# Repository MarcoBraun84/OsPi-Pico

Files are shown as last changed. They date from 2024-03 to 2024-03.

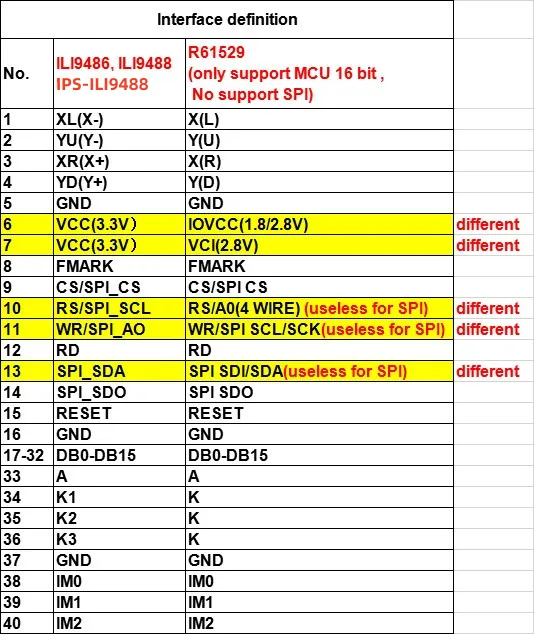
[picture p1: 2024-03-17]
Sonstiges/Pinout ILI9488 Display.webp

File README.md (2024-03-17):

Hier sind alle Projektdatein zum Projekt "OsPi Pico" aus Embedded Systems I vom WS23/24 zu finden.\
Teils wird in "final" und "V1" unterschieden, final bedeutet den Stand am Ende des Projektes, V1 bezieht sich auf die physisch existierenden Platinen.
Sollte an diesen etwas gesucht/geändert werden, kann man sich auzf diese Datein beziehen. Jegliche Verbesserungen oder Weiterentwicklungen sollten aber an den "final" Datein getätigt werden. \

Das Projekt wurde mit Fusion 360 druchgeführt, daher sind viele der umfangreicheren Datein zur Platine nur damit zu öffnen.

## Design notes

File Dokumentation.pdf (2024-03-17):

# PROJEKT OSZI

## „OsPi Pico“ Version 1

## Projektdokumentation

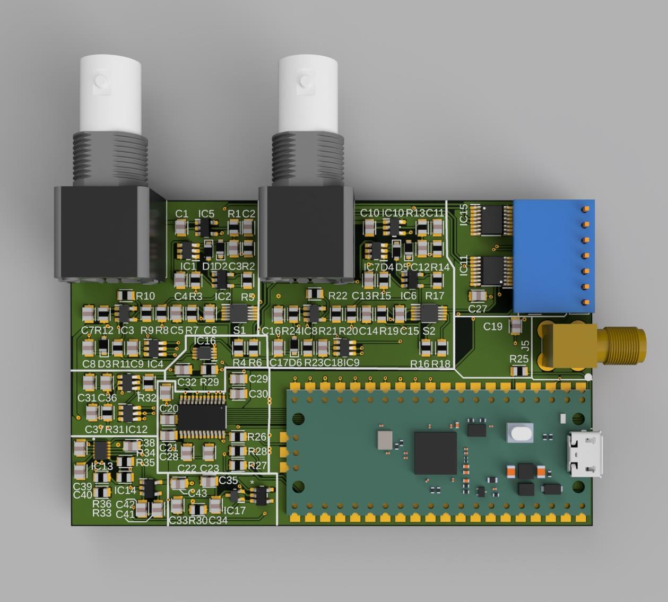
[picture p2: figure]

Embedded Systems I Projekt 2024

Johannes Pautz, Max Sämann

20EIK-IAS

GitHub - Repository (https://github.com/maxsmann/ospi-pico)

## Inhaltsverzeichnis

## 1. Kenndaten

### 1.1 Grundlage: Projekt „RPScope“

Als Grundstein für das Projekt diente das Projekt „RPScope“ (https://hackaday.io/project/188051-rpscope) von „jpgeiro“, welches auf Hackaday.io veröffentlicht wurde. Von hier wurde die Software, sowie der Schaltplan übernommen und überarbeitet. Viele unbekannte Punkte sowie nähere Erklärungen zu Software und Hardware Aufbau sind dort zu finden.

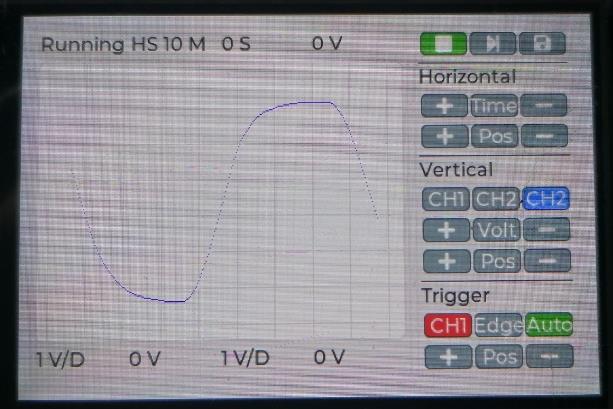
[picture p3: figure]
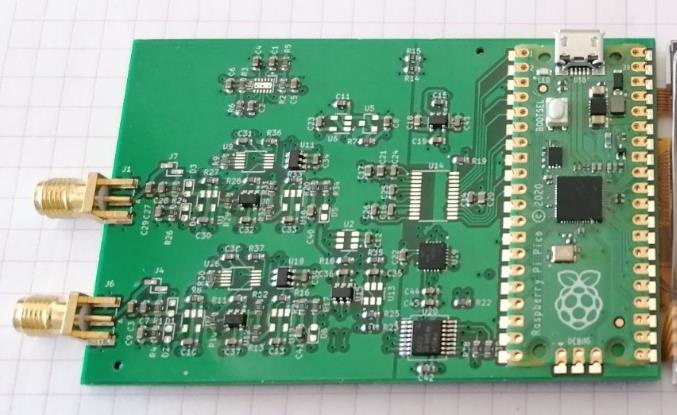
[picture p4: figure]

### 1.2 Eigenschaften der „OsPi Pico“ Platine

- 2 Eingangskanäle mit 100MHz Analog-Bandbreite
- 100Msps ADC mit 8 Bit Auflösung
- 10MHz zur Messung nutzbare Bandbreite pro Kanal
- ±27V Eingangsbereich
- Bedienung über 3,5 Zoll Touch Display
- Stromversorgung über Micro USB (USB-C mit anderem Pi Pico möglich)

## 2. Aufbau

### 2.1 Schaltplan

Die Struktur des Gerätes ist wie folgend aufgebaut:

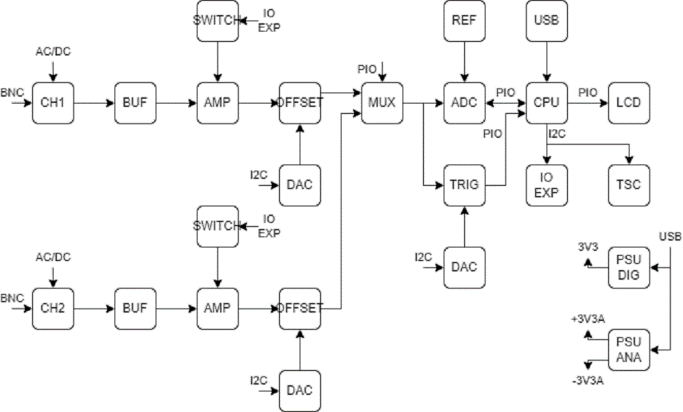
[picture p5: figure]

2.1.1 Belegung Pi Pico

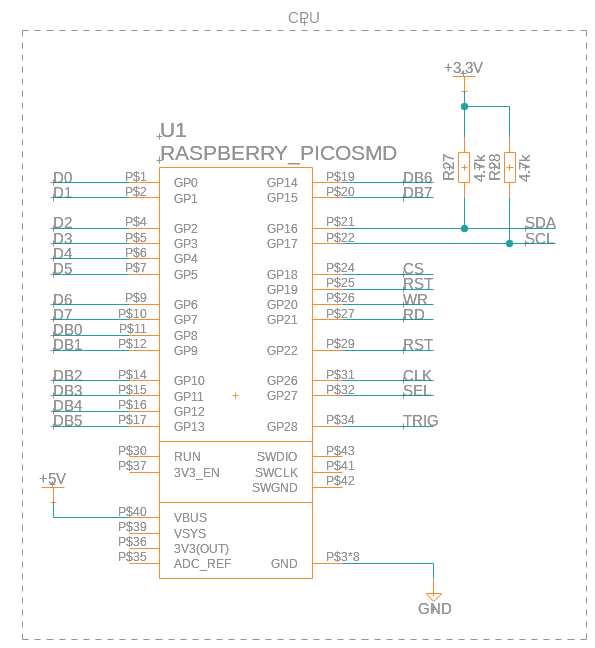
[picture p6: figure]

2.1.2 Stromversorgung Digital

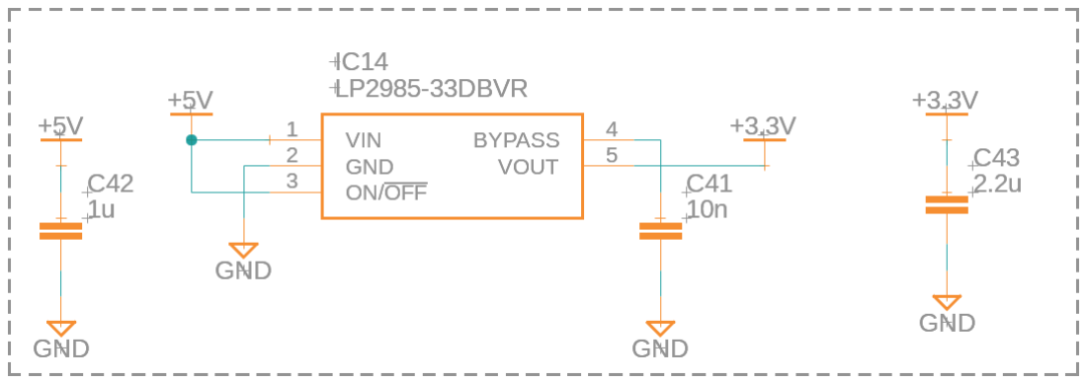
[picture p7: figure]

Die Stromversorgung für den digitalen Teil wird durch einen einfachen Spannungsregler umgesetzt. +5V wird durch den USB-Port am Pi Pico gespeist. Die Kondensatoren C42 und C43 dienen zu Stabilisierung.

C43 kann bei Problemen auch entfernt werden. In unseren Versuchen stellte sich dieser Kondensator nach einiger Zeit als kaputt heraus, was teils bis zum Kurzschluss von +3.3V und somit auch zur Zerstörung des Spannungsreglers folgen kann. Eine Ursache konnte bisher noch nicht ermittelt werden.

2.1.3 Display

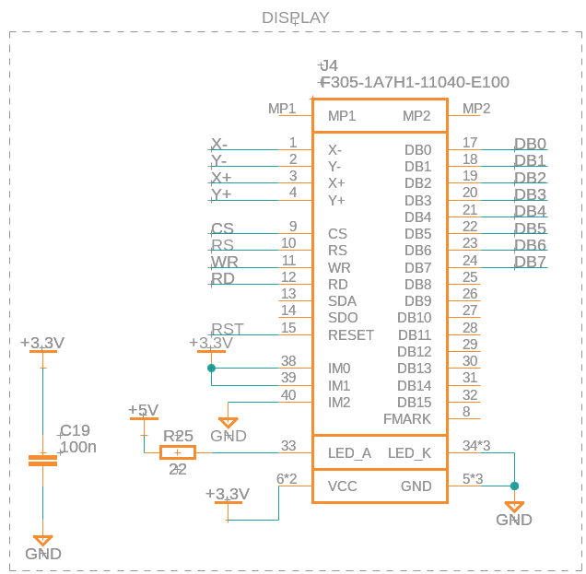
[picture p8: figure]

Das Display ist ein 3,5 Zoll großes resistives Touchdisplay mit einer Auflösung von 480x320 Pixeln. Integriert ist der ILI9488 Displaytreiber. Zu finden ist das Modell auf Aliexpress. (https://de.aliexpress.com/item/32829704426.html)

Das Display ist per 8 Bit parallel Bus nach 8080 Standard an den Pi Pico angebunden. Die Pins 9 bis 12 dienen zur Steuerung des Datenverkehrs.

Leider existiert bisher keine passende Anbindung in der Software für das 8 Bit Interface. Ebenfalls ist auf Charge 1 der Platinen eine Fehlerhafte Verbindung zwischen RST und RS vorhanden.

Näheres zu den Problemen und möglichen Lösungen ist in Kapitel 4 nachzulesen.

Gerät | Pin | Funktion Display Pin | Name | Bemerkung
Touch | 16 | X- | 1 | XL(X-)
Touch | 17 | Y- | 2 | YU(Y-)
Touch | 13 | X+ | 3 | XR(X+)
Touch | 14 | Y+ | 4 | YD(Y+)
PSU¹ | - | GND | 5 | GND
PSU | - | +3.3V | 6 | VCC
PSU | - | +3.3V | 7 | VCC
- | - | - | 8 | FMARK
Pico | 18 | CS | 9 | CS
Pico | 19 | RS | 10 | RS/SCL
Pico | 20 | WR | 11 | WR/AO
Pico | 21 | RD | 12 | RD
- | - | - | 13 | SDA
- | - | - | 14 | SDO
Pico | 22 | RST | 15 | RESET
PSU | - | GND | 16 | GND
Pico | 8-15 | DB0-7 | 17-32 | DB0-15 | Parallel Ansteuerung
PSU | +5V, 22R | Backlight | 33 | A | Anode LED Backlight, +5V durch 22R Wiederstand
PSU | - | GND | 34 | K1 | Kathode LED Backlight
PSU | - | GND | 35 | K2 | Kathode LED Backlight
PSU | - | GND | 36 | K3 | Kathode LED Backlight
PSU | - | GND | 37 | GND
PSU | - | +3.3V | 38 | IM0 | Input Mode: setzt genutzten Eingang fest, hier 8 Bit Parallel
PSU | - | +3.3V | 39 | IM1
PSU | - | GND | 40 | IM2

1 Spannungsversorgung

2.1.4 Touch-Controller

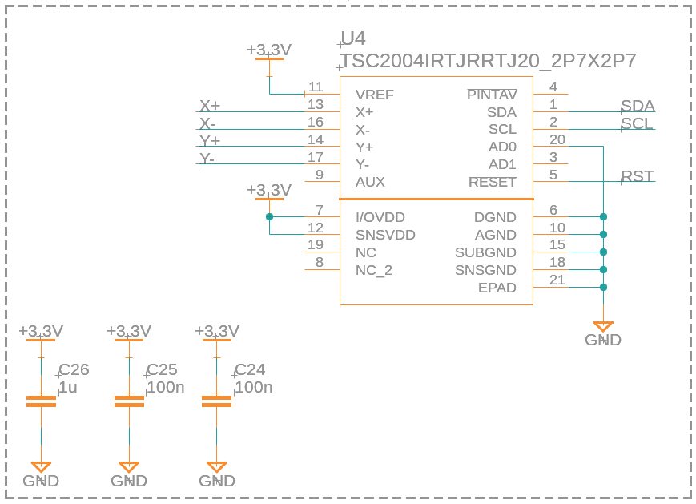
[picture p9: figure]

2.1.5 IO-Expander

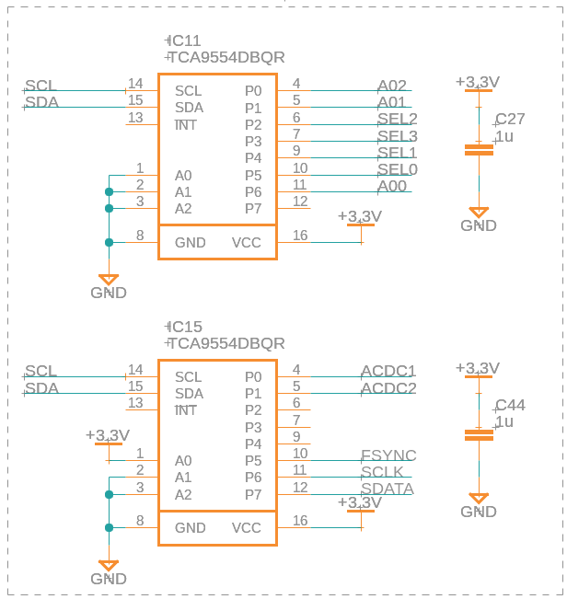
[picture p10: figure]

Der zweite IO-Expander wird im Grunde nur für die AC/DC Umschaltung benötigt. Die Anbindungen FSYNC, SCLK und SDATA vom Funktionsgenerator funktionieren so nicht un müssten umgelegt werden, wie in Kapitel 4 beschrieben.

2.1.6 Funktionsgenerator

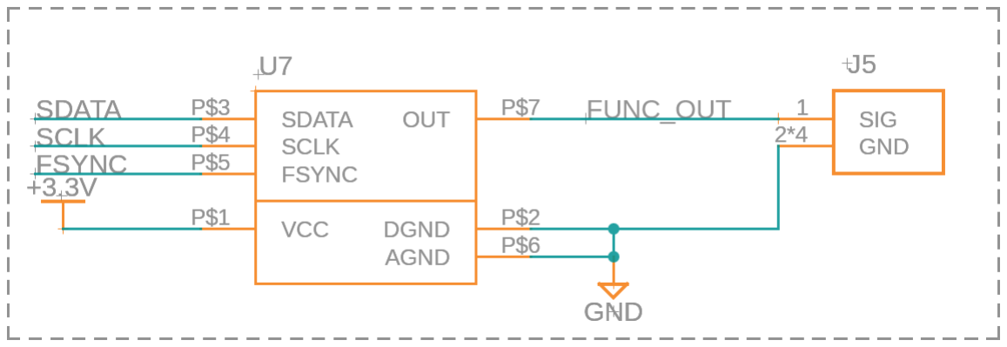
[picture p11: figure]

Der Funktionsgenerator basiert auf einer fertigen Platine mit dem Analog Devices AD9833 IC. Er kann über 3-wire SPI angesteuert werden.

Die Platine selbst wird mit Hilfe einer Steckleiste über der Hauptplatine angebracht. Ein passendes Board kann auf eBay (https://www.ebay.de/itm/284111345234) erworben werden. Da es sich um kein Modell eines wirklich namhaften Herstellers handelt kann folgendes Bild zusammen mit der Modellnummer des ICs als Referenz verwendet werden.

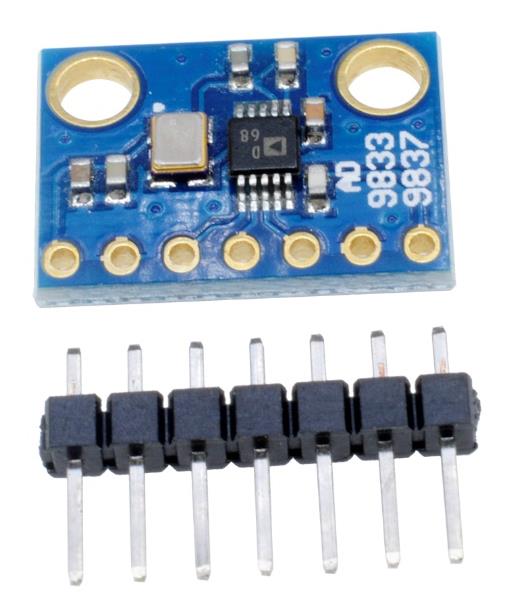
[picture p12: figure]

2.1.7 Stromversorgung analog

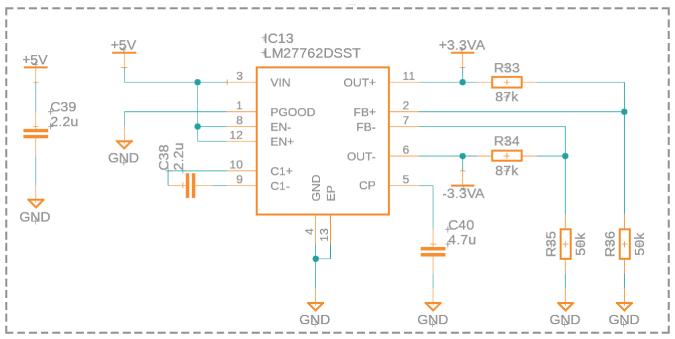
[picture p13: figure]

Die Analoge Stromversorgung wird durch den LM27762 IC ermöglicht. Dieser kann aus der +5VDC Versorgungsspannung sowohl +3.3V als aus -3.3V generieren und ermöglicht so die einfache Nutzung traditioneller OPVs.

2.1.8 Eingangskanäle

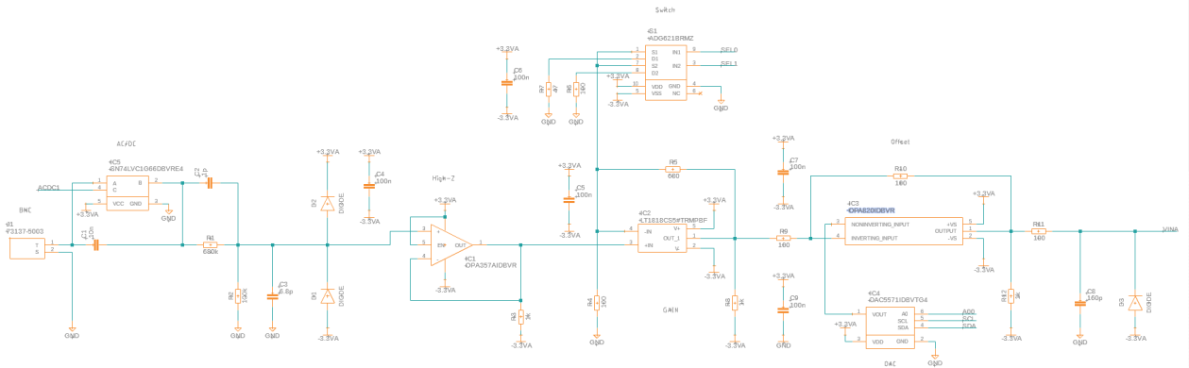
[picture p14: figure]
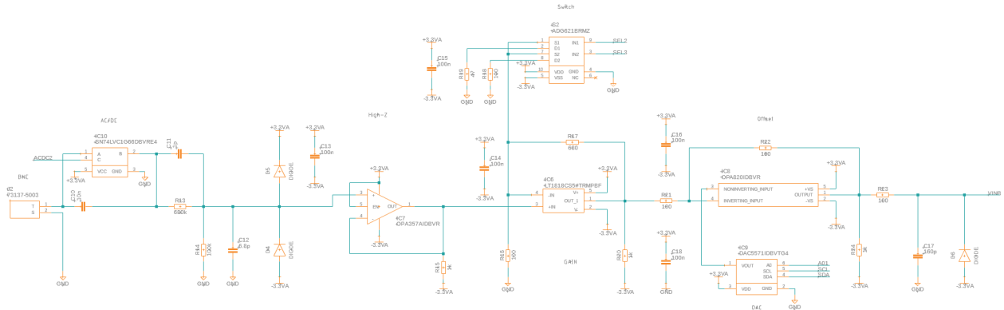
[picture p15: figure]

Die Eingangskanäle bestehen aus 4 Abschnitten. Zuerst kommt die Einkopplung, hier kann auch durch die Analogschalter zwischen AC und DC-Kopplung gewechselt werden. Anschließend kommt die „High-Z“ Stufe, welche dazu dient, die Eingangsimpedanz heraufzusetzen. So werden die Messstrecken nicht durch zusätzliche Stromflüsse belastet, was die Messergebnisse verfälschen würde. Darauf folgt die Gain-Stufe welche je nach gewünschtem Eingangsbereich das Signal „verkleinert“. Die Verstärkung wird durch den Analogschalter oben eingestellt, welcher verschiedene Spannungsteiler darstellt. Am Ende sitzt die Offset-Stufe, hier wird dem Signal eine DC Spannung hinzu gefügt, damit das letztendliche Signal dem 0-VREF Eingangsbereich des ADC entspricht.

2.1.9 Multiplexer

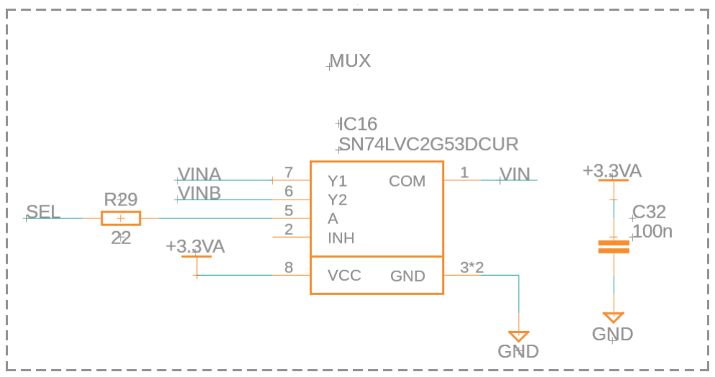
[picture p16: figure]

Normal leitet der Multiplexer Kanal Y1 / VINA auf den Ausgang COM weiter. Liegt SEL am Steuereingang A an, so wird Y1 von COM getrennt und stattdessen Kanal Y2 / VINB auf COM gelegt.

In Betrieb passiert dies blitzschnell um jeweils abwechselnd die Kanäle mit dem ADC samplen zu können.

2.1.10 ADC

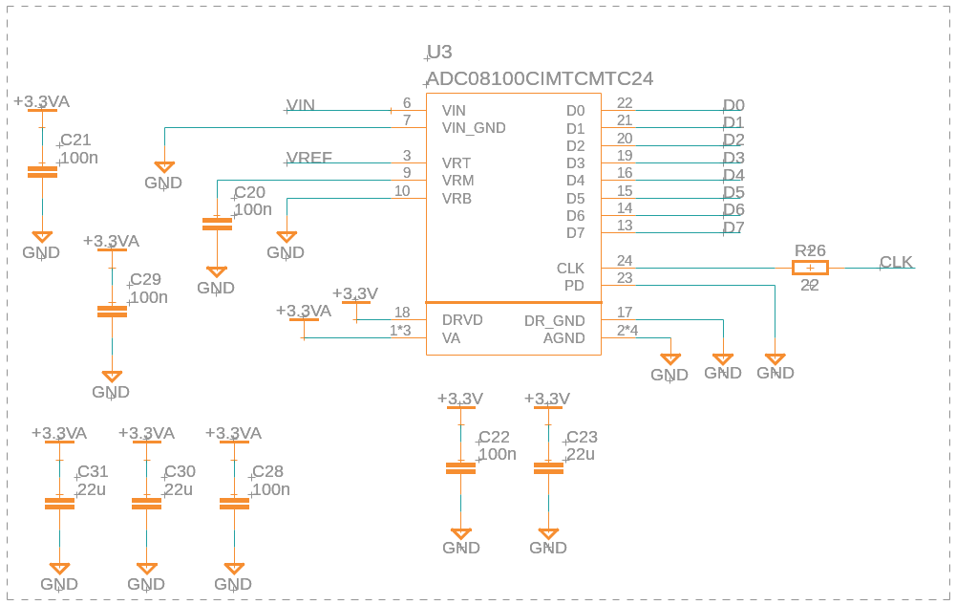
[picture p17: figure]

Der ADC wertet jeweils seinen VIN-Eingang aus, nachdem CLK (vom Pi kommend) von HIGH auf LOW fällt. Bei voller Sample Rate liegt der passende Digitalwert zum VIN Eingang nach 3,5 Samples Verzögerung an den Ausgangspins an.

Der Eingangsbereich beträgt 0V-VREF, in unserem Fall also 0-2V. Das bedeutet, dass das Eingangssignal vorher durch die Offset-Stufe im Analogeingang verschoben werden muss. 0V im Eingangssignal muss zu 1V am ADC Eingang werden.

Die Daten des ADCs werden über 8 Bit parallel Bus (1 Pin für jedes Bit an Auflösung) an den Pi Pico übertragen. Das ermöglicht uns deutlich höheren Durchsatz als zum Beispiel bei I2C oder SPI.

2.1.11 Referenzspannungsquelle

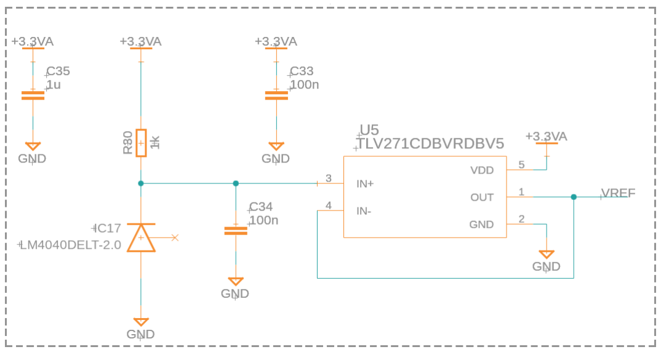
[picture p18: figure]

Die Referenzspannung wird mit Hilfe einer hochgenauen Z-Diode erzeugt. Da diese Referenzspannung aber bei Belastung einbrechen würde, wird ein OPV als Impedanzwandler genutzt, um den Strom über die Z-Diode möglichst nah an 0 zu halten.

2.1.12 Trigger

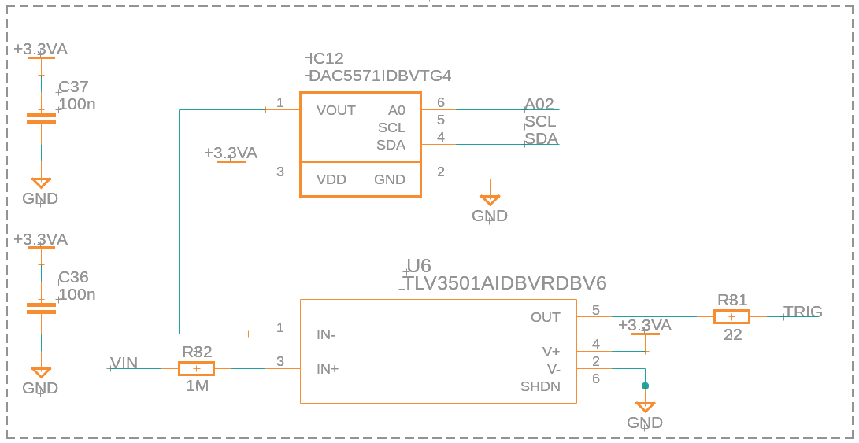
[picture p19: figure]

Das Herzstück des Triggers ist der TLV3501 Highspeed-Komparator. Er gibt über das TRIG-Signal ein HIGH Pegel an den Pi Pico, wenn die Eingestellte Spannung im Eingangssignal erreicht wird. Der Spannungspegel wird durch einen per I2C an den Pico angebundenen DAC eingestellt.

Für VIN sollte VINA verwendet werden, das ist ein Fehler, der beim Layout unterlaufen ist, mehr dazu in Kapitel 4.

### 2.2 Platine

2.2.1 Materialliste

Für das Gerät ergibt sich abgesehen von der Platine selbst und dem Display folgende Materialliste:

Menge | Wert | Bauteil
10 | 100 | R_CHIP-0805(2012-METRIC)
2 | 100k | R_CHIP-0805(2012-METRIC)
23 | 100n | C_CHIP-0805(2012-METRIC)
3 | 10n | C_CHIP-0805(2012-METRIC)
2 | 160p | C_CHIP-0805(2012-METRIC)
1 | 1M | R_CHIP-0805(2012-METRIC)
7 | 1k | R_CHIP-0805(2012-METRIC)
2 | 1p | C_CHIP-0805(2012-METRIC)
5 | 1u | C_CHIP-0805(2012-METRIC)
3 | 2.2u | C_CHIP-0805(2012-METRIC)
4 | 22 | R_CHIP-0805(2012-METRIC)
3 | 22u | C_CHIP-0805(2012-METRIC)
2 | 4.7k | R_CHIP-0805(2012-METRIC)
1 | 4.7u | C_CHIP-0805(2012-METRIC)
2 | 47 | R_CHIP-0805(2012-METRIC)
2 | 50k | R_CHIP-0805(2012-METRIC)
2 | 6.8p | C_CHIP-0805(2012-METRIC)
2 | 680 | R_CHIP-0805(2012-METRIC)
2 | 680k | R_CHIP-0805(2012-METRIC)
2 | 73137-5003 | 73137-5003
2 | 87k | R_CHIP-0805(2012-METRIC)
1 | AD9833FUNCGEN | AD9833FUNCGEN
1 | ADC08100CIMTCMTC24 | ADC08100CIMTCMTC24
2 | ADG621BRMZ | ADG621BRMZ
3 | DAC5571IDBVTG4 | DAC5571IDBVTG4
6 | DIODE | DIODE_DO-219-AC(SOD323F)
1 | F305-1A7H1-11040-E100 | F305-1A7H1-11040-E100
1 | LM27762DSST | LM27762DSST
1 | LM4040DELT-2.0 | LM4040DELT-2.0
1 | LP2985-33DBVR | LP2985-33DBVR
2 | LT1818CS5#TRMPBF | LT1818CS5#TRMPBF
2 | OPA357AIDBVR | OPA357AIDBVR
2 | OPA820IDBVR | OPA820IDBVR
1 | PCB.SMAFRA.HT | PCB.SMAFRA.HT
1 | RASPBERRY_PICOSMD | RASPBERRY_PICOSMD
2 | SN74LVC1G66DBVRE4 | SN74LVC1G66DBVRE4
1 | SN74LVC2G53DCUR | SN74LVC2G53DCUR
2 | TCA9554DBQR | TCA9554DBQR
1 | TLV271CDBVRDBV5 | TLV271CDBVRDBV5
1 | TLV3501AIDBVRDBV6 | TLV3501AIDBVRDBV6
1 | TSC2004IRTJRRTJ20_2P7X2P7 | TSC2004IRTJRRTJ20_2P7X2P7

Alle nicht-Standard SMD-Komponenten sind zur einfacheren Bestellung als Projektliste auf Mouser verfügbar:
https://www.mouser.com/ProjectManager/ProjectDetail.aspx?AccessID=aab402505e

2.2.2 Bestückung

Die | Bestückung | der | einzelnen
Komponenten ist wie folgt:
Part | Value | Device
C1 | 10n | C_CHIP-0805(2012-METRIC)
C2 | 1p | C_CHIP-0805(2012-METRIC)
C3 | 6.8p | C_CHIP-0805(2012-METRIC)
C4 | 100n | C_CHIP-0805(2012-METRIC)
C5 | 100n | C_CHIP-0805(2012-METRIC)
C6 | 100n | C_CHIP-0805(2012-METRIC)
C7 | 100n | C_CHIP-0805(2012-METRIC)
C8 | 160p | C_CHIP-0805(2012-METRIC)
C9 | 100n | C_CHIP-0805(2012-METRIC)
C10 | 10n | C_CHIP-0805(2012-METRIC)
C11 | 1p | C_CHIP-0805(2012-METRIC)
C12 | 6.8p | C_CHIP-0805(2012-METRIC)
C13 | 100n | C_CHIP-0805(2012-METRIC)
C14 | 100n | C_CHIP-0805(2012-METRIC)
C15 | 100n | C_CHIP-0805(2012-METRIC)
C16 | 100n | C_CHIP-0805(2012-METRIC)
C17 | 160p | C_CHIP-0805(2012-METRIC)
C18 | 100n | C_CHIP-0805(2012-METRIC)
C19 | 100n | C_CHIP-0805(2012-METRIC)
C20 | 100n | C_CHIP-0805(2012-METRIC)
C21 | 100n | C_CHIP-0805(2012-METRIC)
C22 | 100n | C_CHIP-0805(2012-METRIC)
C23 | 22u | C_CHIP-0805(2012-METRIC)
C24 | 100n | C_CHIP-0805(2012-METRIC)
C25 | 100n | C_CHIP-0805(2012-METRIC)
C26 | 1u | C_CHIP-0805(2012-METRIC)
C27 | 1u | C_CHIP-0805(2012-METRIC)
C28 | 100n | C_CHIP-0805(2012-METRIC)
C29 | 100n | C_CHIP-0805(2012-METRIC)
C30 | 22u | C_CHIP-0805(2012-METRIC)
C31 | 22u | C_CHIP-0805(2012-METRIC)
C32 | 100n | C_CHIP-0805(2012-METRIC)
C33 | 100n | C_CHIP-0805(2012-METRIC)
C34 | 100n | C_CHIP-0805(2012-METRIC)
C35 | 1u | C_CHIP-0805(2012-METRIC)
C36 | 100n | C_CHIP-0805(2012-METRIC)
C37 | 100n | C_CHIP-0805(2012-METRIC)
C38 | 2.2u | C_CHIP-0805(2012-METRIC)
C39 | 2.2u | C_CHIP-0805(2012-METRIC)
C40 | 4.7u | C_CHIP-0805(2012-METRIC)
C41 | 10n | C_CHIP-0805(2012-METRIC)
C42 | 1u | C_CHIP-0805(2012-METRIC)
C43 | 2.2u | C_CHIP-0805(2012-METRIC)
C44 | 1u | C_CHIP-0805(2012-METRIC)
D1 | DIODE | DIODE_DO-219- AC(SOD323F)
D2 | DIODE | DIODE_DO-219-AC(SOD323F)
D3 | DIODE | DIODE_DO-219-AC(SOD323F)
D4 | DIODE | DIODE_DO-219-AC(SOD323F)
D5 | DIODE | DIODE_DO-219-AC(SOD323F)
D6 | DIODE | DIODE_DO-219-AC(SOD323F)
IC1 | OPA357AIDBVR | OPA357AIDBVR
IC2 | LT1818CS5#TRMPBF | LT1818CS5#TRMPBF
IC3 | OPA820IDBVR | OPA820IDBVR
IC4 | DAC5571IDBVTG4 | DAC5571IDBVTG4
IC5 | SN74LVC1G66DBVR E4 | SN74LVC1G66DBVRE4
IC6 | LT1818CS5#TRMPBF | LT1818CS5#TRMPBF
IC7 | OPA357AIDBVR | OPA357AIDBVR
IC8 | OPA820IDBVR | OPA820IDBVR
IC9 | DAC5571IDBVTG4 | DAC5571IDBVTG4
IC10 | SN74LVC1G66DBVR E4 | SN74LVC1G66DBVRE4
IC11 | TCA9554DBQR | TCA9554DBQR
IC12 | DAC5571IDBVTG4 | DAC5571IDBVTG4
IC13 | LM27762DSST | LM27762DSST
IC14 | LP2985-33DBVR | LP2985-33DBVR
IC15 | TCA9554DBQR | TCA9554DBQR
IC16 | SN74LVC2G53DCUR | SN74LVC2G53DCUR
IC17 | LM4040DELT-2.0 | LM4040DELT-2.0
J1 | 73137-5003 | 73137-5003
J2 | 73137-5003 | 73137-5003
J4 | F305-1A7H1-11040-E100 | F305-1A7H1-11040-E100
J5 | PCB.SMAFRA.HT | PCB.SMAFRA.HT
R1 | 680k | R_CHIP-0805(2012-METRIC)
R2 | 100k | R_CHIP-0805(2012-METRIC)
R3 | 1k | R_CHIP-0805(2012-METRIC)
R4 | 100 | R_CHIP-0805(2012-METRIC)
R5 | 680 | R_CHIP-0805(2012-METRIC)
R6 | 100 | R_CHIP-0805(2012-METRIC)
R7 | 47 | R_CHIP-0805(2012-METRIC)
R8 | 1k | R_CHIP-0805(2012-METRIC)
R9 | 100 | R_CHIP-0805(2012-METRIC)
R10 | 100 | R_CHIP-0805(2012-METRIC)
R11 | 100 | R_CHIP-0805(2012-METRIC)
R12 | 1k | R_CHIP-0805(2012-METRIC)
R13 | 680k | R_CHIP-0805(2012-METRIC)
R14 | 100k | R_CHIP-0805(2012-METRIC)
R15 | 1k | R_CHIP-0805(2012-METRIC)
R16 | 100 | R_CHIP-0805(2012-METRIC)
R17 | 680 | R_CHIP-0805(2012-METRIC)
R18 | 100 | R_CHIP-0805(2012-METRIC)
R19 | 47 | R_CHIP-0805(2012-METRIC)
R20 | 1k | R_CHIP-0805(2012-METRIC)
R21 | 100 | R_CHIP-0805(2012-METRIC)
R22 | 100 | R_CHIP-0805(2012-METRIC)
R23 | 100 | R_CHIP-0805(2012-METRIC)
R24 | 1k | R_CHIP-0805(2012-METRIC)
R25 | 22 | R_CHIP-0805(2012-METRIC)
R26 | 22 | R_CHIP-0805(2012-METRIC)
R27 | 4.7k | R_CHIP-0805(2012-METRIC)
R28 | 4.7k | R_CHIP-0805(2012-METRIC)
R29 | 22 | R_CHIP-0805(2012-METRIC)
R30 | 1k | R_CHIP-0805(2012-METRIC)
R31 | 22 | R_CHIP-0805(2012-METRIC)
R32 | 1M | R_CHIP-0805(2012-METRIC)
R33 | 87k | R_CHIP-0805(2012-METRIC)
R34 | 87k | R_CHIP-0805(2012-METRIC)
R35 | 50k | R_CHIP-0805(2012-METRIC)
R36 | 50k | R_CHIP-0805(2012-METRIC)
S1 | ADG621BRMZ | ADG621BRMZ
S2 | ADG621BRMZ | ADG621BRMZ
U1 | RASPBERRY_PICOS MD | RASPBERRY_PICOSMD
U3 | ADC08100CIMTCMT C24 | ADC08100CIMTCMTC24
U4 | TSC2004IRTJRRTJ20 _2P7X2P7 | TSC2004IRTJRRTJ20_2P7X2 P7
U5 | TLV271CDBVRDBV5 | TLV271CDBVRDBV5
U6 | TLV3501AIDBVRDBV 6 | TLV3501AIDBVRDBV6
U7 | AD9833FUNCGEN | AD9833FUNCGEN

## 3. Software

3.1.1 Programmierung des Pi Pico mit Micropython

Zuerst muss die Firmware von der Raspberry Pi Website heruntergeladen werden und dann auf dem Pi gezogen werden. Dafür hält man den „BOOTSEL“ Knopf am Pico gedrückt, während man diesen per USB verbindet. Dieser taucht als externer Speicher auf dem PC auf, die Firmwaredatei muss nun nur auf diesen Speicher kopiert werden. Anschließend startet der Pico neu und kann nun in der Entwicklungsumgebung gefunden werden. Als Entwicklungsumgebung kann entweder die Thonny DIE oder Visual Studio Code mit der Micropico Erweiterung dienen.

Einzelne .py Code-Dateien können direkt aus der IDE heraus auf dem Pico ausgeführt werden, wenn es sich aber wie in unserem Fall um mehrere Dateien handelt, müssen die Dateien mit Hilfe des in die IDE integrierten Dateibrowsers auf den Pico übertragen werden. Bei größeren Programmen hängt dieser sich gerne während des Kopierens auf, was einen Neustart und eine Neuinstallation der Firmware erforderten. Hier hat sich als wirksam herausgestellt, eine Hälfte zu übertragen, den Pico am USB-Port ab- und wieder anzustecken und dann die zweite Hälfte zu kopieren.

3.1.2 Schwierigkeiten der Nutzung externer Bibliotheken mit Micropython

Für die Nutzeroberfläche des Oszilloskops wird die Grafikbibliothek lvgl ² benötigt, welche offiziell über lv_micropython³ auch die Verwendung unter Micropython unterstützt. In unserem Fall kann aber maximal einer 8.X Version von lvgl verwendet werden, da sich ab Version 9 wieder einige Codes geändert haben.

Zusätzlich stellt sich die Installation mehr als kompliziert heraus. Die passende Firmware für den Pi muss vorerst selbst auf einem Linux Rechner oder auf Windows über WSL kompiliert werden.

Dafür müssen folgende Schritte im Terminal durchlaufen werden:

1 | git clone https://github.com/lvgl/lv_micropython.git
2 | cd lv_micropython
3 | git submodule update --init --recursive lib/lv_bindings
4 | make -C ports/rp2 BOARD=PICO submodules
5 | make -j -C mpy-cross
6 | make -j -C ports/rp2 BOARD=PICO USER_C_MODULES=../../lib/lv_bindings/bindings.cmake

Die benötigte .uf2-Firmwaredatei, in der die Bibliothek integriert wurde, kann bei Erfolg anschließend im Verzeichnis lv_micropyton/Ports/rp2/build-PICO/firmware.uf2 gefunden und auf den Pico kopiert werden.

Dieser Prozess birgt jedoch einige Eigenheiten und neigt dazu, mit kryptischen Fehlermeldungen abzubrechen. In diesem Fall muss der Prozess komplett von neuem

2 https://github.com/lvgl/lvgl

3 https://github.com/lvgl/lv_micropython gestartet werden. Sollte eine Fehlermeldung fehlende Packages wie z.B. gcc-… bemängeln, so sollte vor dem Neustart das Package mit „sudo apt-get install [Packagename]“ installiert werden.

## 4. Bestehende Probleme

4.1.1 Problem Abweichende Software

Leider befindet sich die Software nicht auf dem richtigen Hardwarestand, was dazu führt dass die Platine derzeit nicht nutzbar ist. Einige Komponenten weichen dadurch ab oder können nicht korrekt angesteuert werden. Dadurch ergeben sich folgende Probleme:

Displayanbindung

Das Display ist softwareseitig über den SPI-Bus angebunden, welcher auf dieser Hardware gar nicht genutzt wird. Das Display ist stattdessen übern eine 8 Bit Parallel Anbindung nach 8080 Standard mit den Pins 8 bis 15 des Picos verbunden. Für diese Anbindung liegt kein passender Display Treiber vor.

Umsetzung des Triggers

Der Trigger ist softwareseitig mit PWM direkt über einen Pin des Picos umgesetzt. Auf dem Board ist jedoch schon eine ausgebautere Variante mit Komparator und einem eigenen DAC zur Einstellung der Spannungsschwelle verbaut. Für den DAC existiert eine Einbindung jedoch ist diese sehr simpel und enthält derzeit noch keine Möglichkeit zur Auswahl der einzelnen DACS. Von diesen befinden sich 3 identische auf dem Board (jeweils einer zur Einstellung des Offsets), was die Auswahlpins A00-A02 erfordert. Diese sind aber softwareseitig noch nicht umgesetzt.

Touch Controller

In der Software wird ein XPT2046 Touch Controller verwendet, auf dem Board befindet sich aber das Modell TSC2004 was noch stattdessen implementiert werden müsste. Möglicherweise ist auch der Code für den XPT2046 für den TSC2004 nutzbar.

4.1.2 Fehler im neuen Platinenlayout

Fälschliche Verbindung von RESET und RS

Beim Erstellen der neuen Platine sind ein paar Fehler nicht ausgeblieben. Fälschlicherweise wurden die beiden Steuersignale RESET und RS miteinander verbunden. Eigentlich sollte jedoch RESET einzeln zu Pin 15 am Display und Pin 5 am Touch Controller gehen. Jedoch wurden diese aufgrund von mangelndem Verständnis ebenfalls über Display Pin 10 „RS“ verbunden.
Der Fehler kann durch gezielt Trennung der Leiterbahn zwischen Display und Touch Controller sowie zwischen den RESET und RS-Pin am Pico behoben werden, um zumindest die Display Funktionalität gewährleisten zu können. Jedoch geht so die RESET Funktionalität verloren, dafür müsste ein Draht gelegt werden.

SPI-Anbindung des Funktionsgenerators

Der Funktionsgenerator wird über den SPI-Bus des Pi Pico angebunden, jedoch wurde durch Versäumnis diese Verbindung auf den IO-Expander gelegt. Der IO-Expander ist nicht fähig mit seinen Ein-/Ausgängen einen weiteren SPI-Bus zu erzeugen. Die SPI-Pins des Funktionsgenerators müssten and eine SPI-Schnittstelle des Pi Picos angebunden werden.

Leider ist hier kein geeigneter Pin mehr verfügbar. Würde eine Umstellung des Displays auf SPI erfolgen, könnte der Funktionsgenerator wohlmöglich mit an denselben Bus angebunden werden. So muss dieser Punkt in Schaltplan sowie dem Platinenlayout überarbeitet werden.

### 4.2 Mögliche Problemlösungen

4.2.1 Displayansteuerung

Um das Display korrekt nutzen zu können, könnten zwei Herangehensweisen genutzt werden:

Neuer Displaytreiber

Damit das Display über den 8 Bit 8080 Parallel-Port genutzt werden kann, muss ein passender Display Treiber gefunden und angepasst / geschrieben werden. Vorteil davon wäre, dass das Display über diese Schnittstelle deutlich schneller angesteuert werden kann als über SPI, da auch die 8-fache Bandbreite zur Verfügung steht. So ließen sich in etwa 60 Bilder/Sekunde realisieren, das Display unterstützt maximal 70.

Anbindung auf SPI umbauen

Durch Drähte oder eine neue Platine könnte das Display wieder, wie in der Software spezifiziert per SPI angebunden werden. Hierfür würden die Pins am Pico frei werden, welche vorher für die parallele Übertragung genutzt wurden. Daraus würde sich folgende Belegung am Display ergeben:

Gerät | Pin | Funktion Display Pin | Name | Bemerkung
Touch | 16 | X- | 1 | XL(X-)
Touch | 17 | Y- | 2 | YU(Y-)
Touch | 13 | X+ | 3 | XR(X+)
Touch | 14 | Y+ | 4 | YD(Y+)
PSU | - | GND | 5 | GND
PSU | - | +3.3V | 6 | VCC
PSU | - | +3.3V | 7 | VCC
- | - | - | 8 | FMARK
Pico | 9 | CS | 9 | CS
Pico | 10 | SCL | 10 | RS/SCL
Pico | 8 | AO/DC | 11 | WR/AO
- | - | - | 12 | RD
Pico | 11 | MOSI | 13 | SDA
Pico | 12 | MISO | 14 | SDO
Pico | 22 | RST | 15 | RESET
PSU | - | GND | 16 | GND
- | - | - | 17-32 | DB0-15 | Parallel Ansteuerung
PSU | 22R | Backlight | 33 | A | Anode LED Backlight
PSU | - | GND | 34 | K1 | Kathode LED Backlight
PSU | - | GND | 35 | K2 | Kathode LED Backlight
PSU | - | GND | 36 | K3 | Kathode LED Backlight
PSU | - | GND | 37 | GND
PSU | - | +3.3V | 38 | IM0 | Input Mode: setzt genutzten Eingang fest, hier 4 Wire SPI
PSU | - | +3.3V | 39 | IM1
PSU | - | +3.3V | 40 | IM2

Im Vergleich zur parallelen Anbindung kann das Display nicht so schnell aktualisiert werden, jedoch sollte ein Oszilloskop auch mit grade mal 10 Bildern/Sekunde⁴ nutzbar sein. Nach eigenem Empfinden würde die Pin-Ersparnis und die Verfügbarkeit fertiger Bibliotheken hier zum Vorteil von SPI überwiegen.

4.2.2 Softwareanpassung

Trigger

Damit der Trigger wie gewollt funktioniert, muss der PWM-Wert, der von der Scope Funktion ausgegeben wird in den passenden Wert für den DAC5571 IC in der Trigger Schaltung gewandelt werden. Schließlich muss dieser Wert noch auf den IC übertragen werden, indem der Adress-Pin A02 HIGH gesetzt werden und die passenden Daten über I2C ausgegeben werden. Währenddessen müssen die Pins A00 und A01 der identischen DACs für den Offset der Eingänge LOW gezogen werden. Das Trigger Signal selbst erfolgt dann über das TRIG-Signal, welches als Eingang im Pi Pico umgesetzt werden müsste und dort an die Nutzeroberfläche übermittelt werden muss.

Die genaue Adressierung kann auf Seite 15 des Datenblatts⁵ nachgelesen werden.

4.2.3 Verbesserung des Platinenlayouts

Behebung RS/RST Verbindung

Um die Reset-Verbindung korrekt umzusetzen, wird diese vom RS-Potenzial getrennt und eine eigene Leiterbahn gelegt. Das wurde bereits in der aktuellen Version des Layouts korrigiert.

+3.3VA und +3.3V Güsse durch GND-Guss ersetzen

Für eine neue Revision der Platine sollten die Polygongüsse für +3.3VA und +3.3V auf der Oberseite entfernt und durch GND-Güsse ersetzt werden. Dadurch können einige Vias und GND-Leiterbahnen entfernt werden. Dafür müssen nun für die Spannungsversorgung neue Leiterbahnen verlegt werden.

Montagepunkte

Ein kleines, aber nicht unwichtiges Manko der aktuellen Revision sind fehlende Montagepunkte, wie z.B. Löcher für Schrauben/Abstandshalter. Solche Merkmale sollten hinzugefügt werden.

4
https://www.reddit.com/r/esp32/comments/r5awqp/made_a_refresh_rate_test_comparison_between_the/

5 https://www.ti.com/lit/ds/symlink/dac5571.pdf

## 5. Fazit

### 5.1 Stand zu Projektende

Zu Projektende ist das Gerät nicht funktionsfähig. Das rührt aus einer Kombination von Hardwareproblemen und dem, dass die Software in ihrer jetzigen Form nicht mit der Platine funktioniert. Bis zur Präsentation wird probiert zumindest das Display mit neuem C-Code etwas anzeigen zu lassen. Es existiert eine Platine auf der alles bis auf den zweiten Eingangskanal aufgebaut und funktionsfähig ist.

### 5.2 Offene Punkte

- Displayansteuerung durch passenden Displaytreiber oder Hardwareänderung auf SPI realisieren
- Frequenzgenerator per SPI anbinden, bzw. wenn das Display parallel laufen soll Alternative finden oder komplett weglassen
- Berechnung von RMS und Frequenzwerten in der Benutzeroberfläche
- Firmware verstehen und anpassen oder bestenfalls in C neu schreiben
- Montagepunkte zur Platine hinzufügen
- Gehäuse für das Gerät

Leider endet das Projekt nicht mit einem vorzeigbaren funktionierenden Gerät.

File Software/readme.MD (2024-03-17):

Es existieren 3 verschiedene Softwareversionen:\
### original_fixed
Die vollständige Originalsoftware, so abgeändert dass main.py und scope.py fehlerfrei laufen\
(Behebung lv.color_SIZE und zu großer Speicherbedarf) 

### simple_test.py
Dieses kurze Skript liest die Daten der Datenbus Pins per normalem Code und gibt diese auf dem Terminal aus, zusätzlich wird ein passende Clock Signal generiert.\
Dient nur zu simplen Testzwecken 

### measure_only
Entpsricht dem Originalcode, jedoch wurde alles was mit der Nutzeroberfläche oder demm Display zutun hat entfernt. Dient der reinen Analogwertaufnahme (wenn funktional implementiert) 

---

Bei den .uf2 Datein ahndelt es sich um Firmwaredatein für den Pi Pico, einerseits der normalen Micropython Firmware und 2 Micropython Firmware Datein in die die LVGL Bibliothek für Micropython integriert wurde.\
Der Code ist nur mit LVGL Version 8 kompatibel.

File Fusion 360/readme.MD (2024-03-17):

Leider sind die Fusion Projektdatein zu groß für GitHub, sie sind aber auf OneDrive verfügbar:\
[Final](https://1drv.ms/u/s!AjAQl3kyYOWWgpkU1GAGeOEMiVDFZA?e=RxkBtG)\
[Platine V1](https://1drv.ms/u/s!AjAQl3kyYOWWgplNd12sBZf5nOz-AA?e=046h1U)

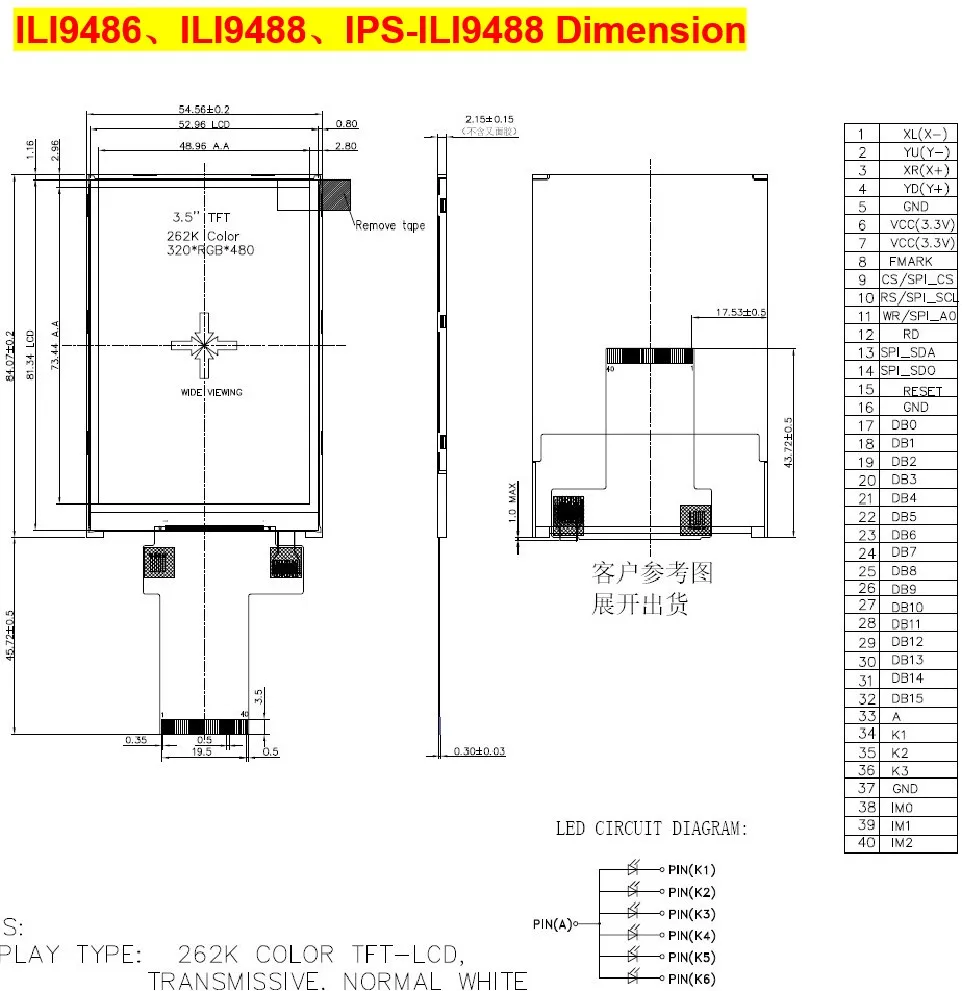
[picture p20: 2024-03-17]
Sonstiges/Maße, Pinout ILI9488 Display.webp

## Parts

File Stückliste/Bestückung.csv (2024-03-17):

Part | Value | Device | Package | Description
C1 | 10n | C_CHIP-0805(2012-METRIC) | CAPC2012X110 | Capacitor - Generic
C2 | 1p | C_CHIP-0805(2012-METRIC) | CAPC2012X110 | Capacitor - Generic
C3 | 6.8p | C_CHIP-0805(2012-METRIC) | CAPC2012X110 | Capacitor - Generic
C4 | 100n | C_CHIP-0805(2012-METRIC) | CAPC2012X110 | Capacitor - Generic
C5 | 100n | C_CHIP-0805(2012-METRIC) | CAPC2012X110 | Capacitor - Generic
C6 | 100n | C_CHIP-0805(2012-METRIC) | CAPC2012X110 | Capacitor - Generic
C7 | 100n | C_CHIP-0805(2012-METRIC) | CAPC2012X110 | Capacitor - Generic
C8 | 160p | C_CHIP-0805(2012-METRIC) | CAPC2012X110 | Capacitor - Generic
C9 | 100n | C_CHIP-0805(2012-METRIC) | CAPC2012X110 | Capacitor - Generic
C10 | 10n | C_CHIP-0805(2012-METRIC) | CAPC2012X110 | Capacitor - Generic
C11 | 1p | C_CHIP-0805(2012-METRIC) | CAPC2012X110 | Capacitor - Generic
C12 | 6.8p | C_CHIP-0805(2012-METRIC) | CAPC2012X110 | Capacitor - Generic
C13 | 100n | C_CHIP-0805(2012-METRIC) | CAPC2012X110 | Capacitor - Generic
C14 | 100n | C_CHIP-0805(2012-METRIC) | CAPC2012X110 | Capacitor - Generic
C15 | 100n | C_CHIP-0805(2012-METRIC) | CAPC2012X110 | Capacitor - Generic
C16 | 100n | C_CHIP-0805(2012-METRIC) | CAPC2012X110 | Capacitor - Generic
C17 | 160p | C_CHIP-0805(2012-METRIC) | CAPC2012X110 | Capacitor - Generic
C18 | 100n | C_CHIP-0805(2012-METRIC) | CAPC2012X110 | Capacitor - Generic
C19 | 100n | C_CHIP-0805(2012-METRIC) | CAPC2012X110 | Capacitor - Generic
C20 | 100n | C_CHIP-0805(2012-METRIC) | CAPC2012X110 | Capacitor - Generic
C21 | 100n | C_CHIP-0805(2012-METRIC) | CAPC2012X110 | Capacitor - Generic
C22 | 100n | C_CHIP-0805(2012-METRIC) | CAPC2012X110 | Capacitor - Generic
C23 | 22u | C_CHIP-0805(2012-METRIC) | CAPC2012X110 | Capacitor - Generic
C24 | 100n | C_CHIP-0805(2012-METRIC) | CAPC2012X110 | Capacitor - Generic
C25 | 100n | C_CHIP-0805(2012-METRIC) | CAPC2012X110 | Capacitor - Generic
C26 | 1u | C_CHIP-0805(2012-METRIC) | CAPC2012X110 | Capacitor - Generic
C27 | 1u | C_CHIP-0805(2012-METRIC) | CAPC2012X110 | Capacitor - Generic
C28 | 100n | C_CHIP-0805(2012-METRIC) | CAPC2012X110 | Capacitor - Generic
C29 | 100n | C_CHIP-0805(2012-METRIC) | CAPC2012X110 | Capacitor - Generic
C30 | 22u | C_CHIP-0805(2012-METRIC) | CAPC2012X110 | Capacitor - Generic
C31 | 22u | C_CHIP-0805(2012-METRIC) | CAPC2012X110 | Capacitor - Generic
C32 | 100n | C_CHIP-0805(2012-METRIC) | CAPC2012X110 | Capacitor - Generic
C33 | 100n | C_CHIP-0805(2012-METRIC) | CAPC2012X110 | Capacitor - Generic
C34 | 100n | C_CHIP-0805(2012-METRIC) | CAPC2012X110 | Capacitor - Generic
C35 | 1u | C_CHIP-0805(2012-METRIC) | CAPC2012X110 | Capacitor - Generic
C36 | 100n | C_CHIP-0805(2012-METRIC) | CAPC2012X110 | Capacitor - Generic
C37 | 100n | C_CHIP-0805(2012-METRIC) | CAPC2012X110 | Capacitor - Generic
C38 | 2.2u | C_CHIP-0805(2012-METRIC) | CAPC2012X110 | Capacitor - Generic
C39 | 2.2u | C_CHIP-0805(2012-METRIC) | CAPC2012X110 | Capacitor - Generic
C40 | 4.7u | C_CHIP-0805(2012-METRIC) | CAPC2012X110 | Capacitor - Generic
C41 | 10n | C_CHIP-0805(2012-METRIC) | CAPC2012X110 | Capacitor - Generic
C42 | 1u | C_CHIP-0805(2012-METRIC) | CAPC2012X110 | Capacitor - Generic
C43 | 2.2u | C_CHIP-0805(2012-METRIC) | CAPC2012X110 | Capacitor - Generic
C44 | 1u | C_CHIP-0805(2012-METRIC) | CAPC2012X110 | Capacitor - Generic
D1 | DIODE | DIODE_DO-219-AC(SOD323F) | SODFL2513X70 | Diode Rectifier - Generic
D2 | DIODE | DIODE_DO-219-AC(SOD323F) | SODFL2513X70 | Diode Rectifier - Generic
D3 | DIODE | DIODE_DO-219-AC(SOD323F) | SODFL2513X70 | Diode Rectifier - Generic
D4 | DIODE | DIODE_DO-219-AC(SOD323F) | SODFL2513X70 | Diode Rectifier - Generic
D5 | DIODE | DIODE_DO-219-AC(SOD323F) | SODFL2513X70 | Diode Rectifier - Generic
D6 | DIODE | DIODE_DO-219-AC(SOD323F) | SODFL2513X70 | Diode Rectifier - Generic
IC1 | OPA357AIDBVR | OPA357AIDBVR | SOT95P280X145-6N | Texas Instruments OPA300AIDBVT Op Amp, 150MHz CMOS, Rail to Rail, 3 V, 5 V, 6-Pin SOT-23
IC2 | LT1818CS5#TRMPBF | LT1818CS5#TRMPBF | SOT95P280X100-5N | OP Amp Single Volt Fdbk +/-6.3V/12.6V Automotive 5-Pin TSOT-23 T/R
IC3 | OPA820IDBVR | OPA820IDBVR | SOT95P280X145-5N | Unity Gain Stable,Low Noise,Voltage Feedback Operational Amplifier
IC4 | DAC5571IDBVTG4 | DAC5571IDBVTG4 | SOT95P280X145-6N | Digital to Analog Converters - DAC Low-power 8-Bit w/hi-speed I2C Input
IC5 | SN74LVC1G66DBVRE4 | SN74LVC1G66DBVRE4 | SOT95P280X145-5N | Analogue Switch ICs Single Bilateral Analog Switch
IC6 | LT1818CS5#TRMPBF | LT1818CS5#TRMPBF | SOT95P280X100-5N | OP Amp Single Volt Fdbk +/-6.3V/12.6V Automotive 5-Pin TSOT-23 T/R
IC7 | OPA357AIDBVR | OPA357AIDBVR | SOT95P280X145-6N | Texas Instruments OPA300AIDBVT Op Amp, 150MHz CMOS, Rail to Rail, 3 V, 5 V, 6-Pin SOT-23
IC8 | OPA820IDBVR | OPA820IDBVR | SOT95P280X145-5N | Unity Gain Stable,Low Noise,Voltage Feedback Operational Amplifier
IC9 | DAC5571IDBVTG4 | DAC5571IDBVTG4 | SOT95P280X145-6N | Digital to Analog Converters - DAC Low-power 8-Bit w/hi-speed I2C Input
IC10 | SN74LVC1G66DBVRE4 | SN74LVC1G66DBVRE4 | SOT95P280X145-5N | Analogue Switch ICs Single Bilateral Analog Switch
IC11 | TCA9554DBQR | TCA9554DBQR | SOP64P600X175-16N | Remote 8-Bit I2C and SMBus I/O Expander
IC12 | DAC5571IDBVTG4 | DAC5571IDBVTG4 | SOT95P280X145-6N | Digital to Analog Converters - DAC Low-power 8-Bit w/hi-speed I2C Input
IC13 | LM27762DSST | LM27762DSST | SON50P200X300X80-13N | Low-Noise Positive- and Negative-Output Charge Pump With Integrated LDO
IC14 | LP2985-33DBVR | LP2985-33DBVR | SOT95P280X145-5N | 150-mA Low-noise Low-dropout Regulator With Shutdown
IC15 | TCA9554DBQR | TCA9554DBQR | SOP64P600X175-16N | Remote 8-Bit I2C and SMBus I/O Expander
IC16 | SN74LVC2G53DCUR | SN74LVC2G53DCUR | SOP50P310X90-8N | Single Pole, Double-Throw (SPDT) Analog Switch or 2:1 Analog Multiplexer/Demultiplexer
IC17 | LM4040DELT-2.0 | LM4040DELT-2.0 | SOT65P210X110-3N | Precision micropower shunt voltage reference
J1 | 73137-5003 | 73137-5003 | 731375003 | Molex BNC Series Right Angle 50 PCB Mount Bulkhead Fitting BNC Connector, jack, Nickel, Through Hole Termination
J2 | 73137-5003 | 73137-5003 | 731375003 | Molex BNC Series Right Angle 50 PCB Mount Bulkhead Fitting BNC Connector, jack, Nickel, Through Hole Termination
J4 | F305-1A7H1-11040-E100 | F305-1A7H1-11040-E100 | F3051A7H111040E100 | Flex Connector, 0.50mm Pitch, Height 2.00mm, Right angle, Flip type, 40 position, With MYLAR
J5 | PCB.SMAFRA.HT | PCB.SMAFRA.HT | PCBSMAFRAHT | RF Connectors / Coaxial Connectors SMA RA PCB Mount, Jack, Gold, 50 , Through Hole Pin
R1 | 680k | R_CHIP-0805(2012-METRIC) | RESC2012X65 | Resistor Fixed - Generic
R2 | 100k | R_CHIP-0805(2012-METRIC) | RESC2012X65 | Resistor Fixed - Generic
R3 | 1k | R_CHIP-0805(2012-METRIC) | RESC2012X65 | Resistor Fixed - Generic
R4 | 100 | R_CHIP-0805(2012-METRIC) | RESC2012X65 | Resistor Fixed - Generic
R5 | 680 | R_CHIP-0805(2012-METRIC) | RESC2012X65 | Resistor Fixed - Generic
R6 | 100 | R_CHIP-0805(2012-METRIC) | RESC2012X65 | Resistor Fixed - Generic
R7 | 47 | R_CHIP-0805(2012-METRIC) | RESC2012X65 | Resistor Fixed - Generic
R8 | 1k | R_CHIP-0805(2012-METRIC) | RESC2012X65 | Resistor Fixed - Generic
R9 | 100 | R_CHIP-0805(2012-METRIC) | RESC2012X65 | Resistor Fixed - Generic
R10 | 100 | R_CHIP-0805(2012-METRIC) | RESC2012X65 | Resistor Fixed - Generic
R11 | 100 | R_CHIP-0805(2012-METRIC) | RESC2012X65 | Resistor Fixed - Generic
R12 | 1k | R_CHIP-0805(2012-METRIC) | RESC2012X65 | Resistor Fixed - Generic
R13 | 680k | R_CHIP-0805(2012-METRIC) | RESC2012X65 | Resistor Fixed - Generic
R14 | 100k | R_CHIP-0805(2012-METRIC) | RESC2012X65 | Resistor Fixed - Generic
R15 | 1k | R_CHIP-0805(2012-METRIC) | RESC2012X65 | Resistor Fixed - Generic
R16 | 100 | R_CHIP-0805(2012-METRIC) | RESC2012X65 | Resistor Fixed - Generic
R17 | 680 | R_CHIP-0805(2012-METRIC) | RESC2012X65 | Resistor Fixed - Generic
R18 | 100 | R_CHIP-0805(2012-METRIC) | RESC2012X65 | Resistor Fixed - Generic
R19 | 47 | R_CHIP-0805(2012-METRIC) | RESC2012X65 | Resistor Fixed - Generic
R20 | 1k | R_CHIP-0805(2012-METRIC) | RESC2012X65 | Resistor Fixed - Generic
R21 | 100 | R_CHIP-0805(2012-METRIC) | RESC2012X65 | Resistor Fixed - Generic
R22 | 100 | R_CHIP-0805(2012-METRIC) | RESC2012X65 | Resistor Fixed - Generic
R23 | 100 | R_CHIP-0805(2012-METRIC) | RESC2012X65 | Resistor Fixed - Generic
R24 | 1k | R_CHIP-0805(2012-METRIC) | RESC2012X65 | Resistor Fixed - Generic
R25 | 22 | R_CHIP-0805(2012-METRIC) | RESC2012X65 | Resistor Fixed - Generic
R26 | 22 | R_CHIP-0805(2012-METRIC) | RESC2012X65 | Resistor Fixed - Generic
R27 | 4.7k | R_CHIP-0805(2012-METRIC) | RESC2012X65 | Resistor Fixed - Generic
R28 | 4.7k | R_CHIP-0805(2012-METRIC) | RESC2012X65 | Resistor Fixed - Generic
R29 | 22 | R_CHIP-0805(2012-METRIC) | RESC2012X65 | Resistor Fixed - Generic
R30 | 1k | R_CHIP-0805(2012-METRIC) | RESC2012X65 | Resistor Fixed - Generic
R31 | 22 | R_CHIP-0805(2012-METRIC) | RESC2012X65 | Resistor Fixed - Generic
R32 | 1M | R_CHIP-0805(2012-METRIC) | RESC2012X65 | Resistor Fixed - Generic
R33 | 87k | R_CHIP-0805(2012-METRIC) | RESC2012X65 | Resistor Fixed - Generic
R34 | 87k | R_CHIP-0805(2012-METRIC) | RESC2012X65 | Resistor Fixed - Generic
R35 | 50k | R_CHIP-0805(2012-METRIC) | RESC2012X65 | Resistor Fixed - Generic
R36 | 50k | R_CHIP-0805(2012-METRIC) | RESC2012X65 | Resistor Fixed - Generic
S1 | ADG621BRMZ | ADG621BRMZ | SOP50P490X110-10N | ADG621BRMZ, Analogue Switch Dual SPST, 3, 5V, 10-Pin, MSOP
S2 | ADG621BRMZ | ADG621BRMZ | SOP50P490X110-10N | ADG621BRMZ, Analogue Switch Dual SPST, 3, 5V, 10-Pin, MSOP
U1 | RASPBERRY_PICOSMD | RASPBERRY_PICOSMD | PICO-PKG-SMD | Raspberry Pi Pico
U3 | ADC08100CIMTCMTC24 | ADC08100CIMTCMTC24 | MTC24
U4 | TSC2004IRTJRRTJ20_2P7X2P7 | TSC2004IRTJRRTJ20_2P7X2P7 | RTJ20_2P7X2P7
U5 | TLV271CDBVRDBV5 | TLV271CDBVRDBV5 | DBV5
U6 | TLV3501AIDBVRDBV6 | TLV3501AIDBVRDBV6 | DBV6
U7 | AD9833FUNCGEN | AD9833FUNCGEN | AD9833FUNCGEN

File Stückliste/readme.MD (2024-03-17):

### Eine vollständige Bestellung exklusive Platine selbst und Display kann hier als [Mouser Projekt](https://www.mouser.com/ProjectManager/ProjectDetail.aspx?AccessID=aab402505e) gefunden werden.
### Das Display kann auf [Aliexpress](https://de.aliexpress.com/item/32829704426.html) gefunden werden. Sollte der Link inaktiv werden, sollte mit der Suchanfrage "3,5 Zoll ILI9488 Resistiv Touch" ein passendes Modell auffindbar sein.

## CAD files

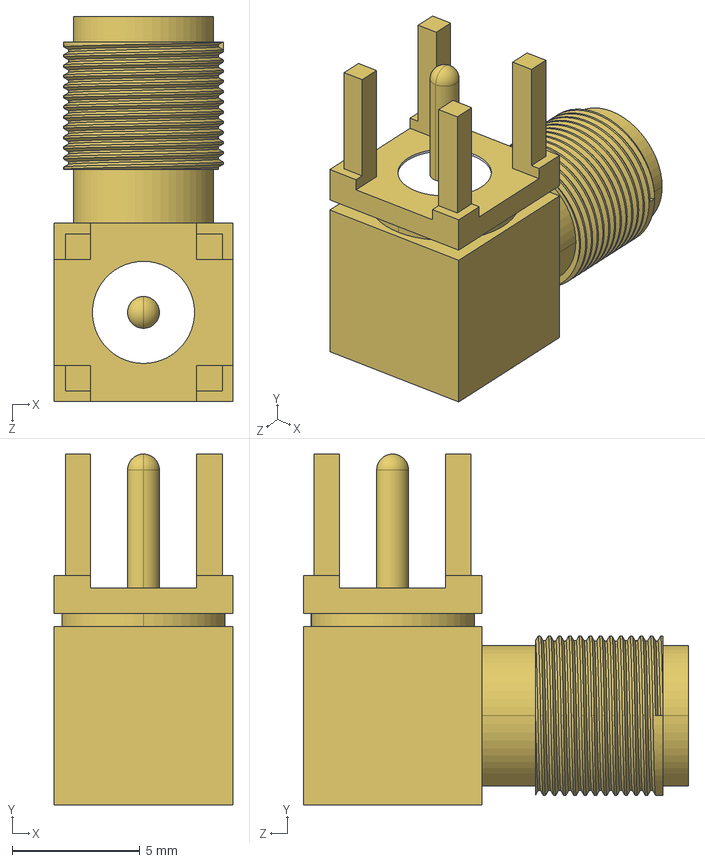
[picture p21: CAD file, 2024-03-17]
Fusion 360/Elektronik Libs/PCB.SMAFRA.HT.stp
7.00 x 13.8 x 15.1 mm

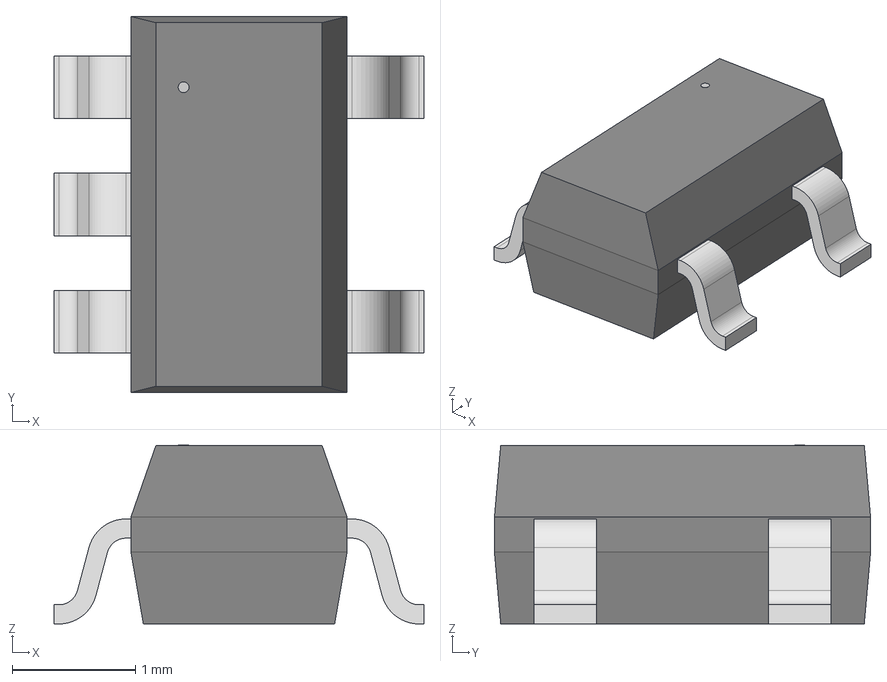
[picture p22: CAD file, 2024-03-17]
Fusion 360/Elektronik Libs/DBV5.step
3.00 x 3.05 x 1.45 mm

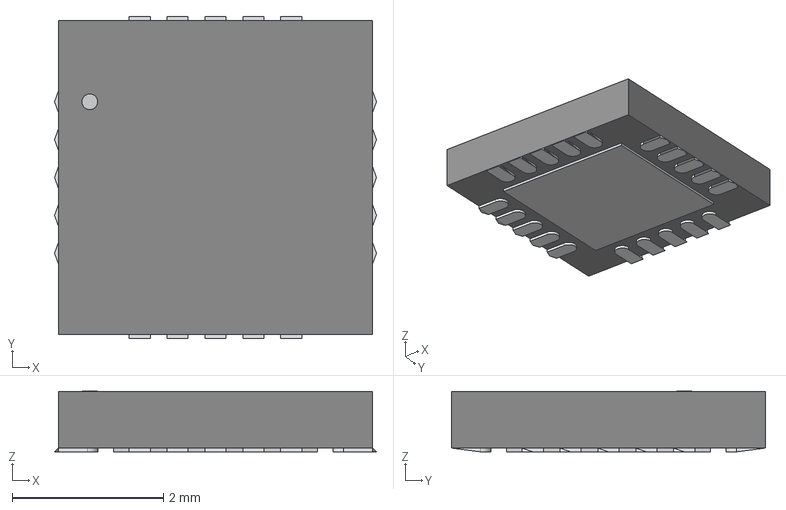
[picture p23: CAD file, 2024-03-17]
Fusion 360/Elektronik Libs/RTJ20_2P7X2P7.step
4.25 x 4.25 x 0.803 mm

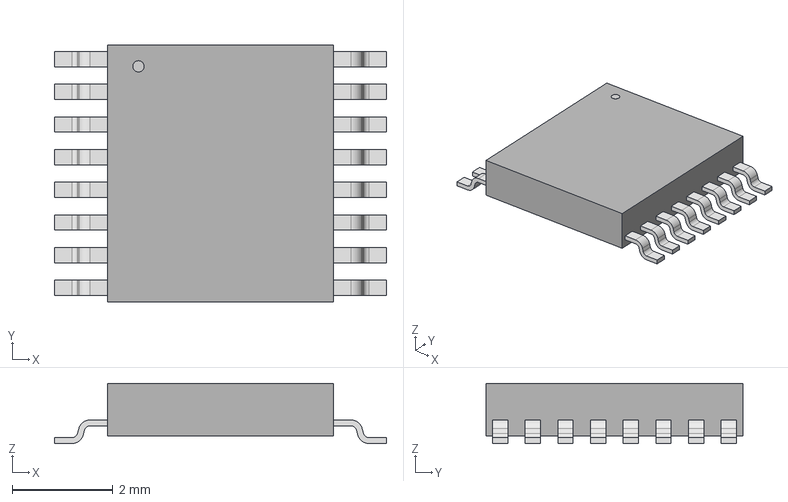
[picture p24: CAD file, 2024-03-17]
Fusion 360/Elektronik Libs/PW16.step
6.60 x 5.11 x 1.20 mm

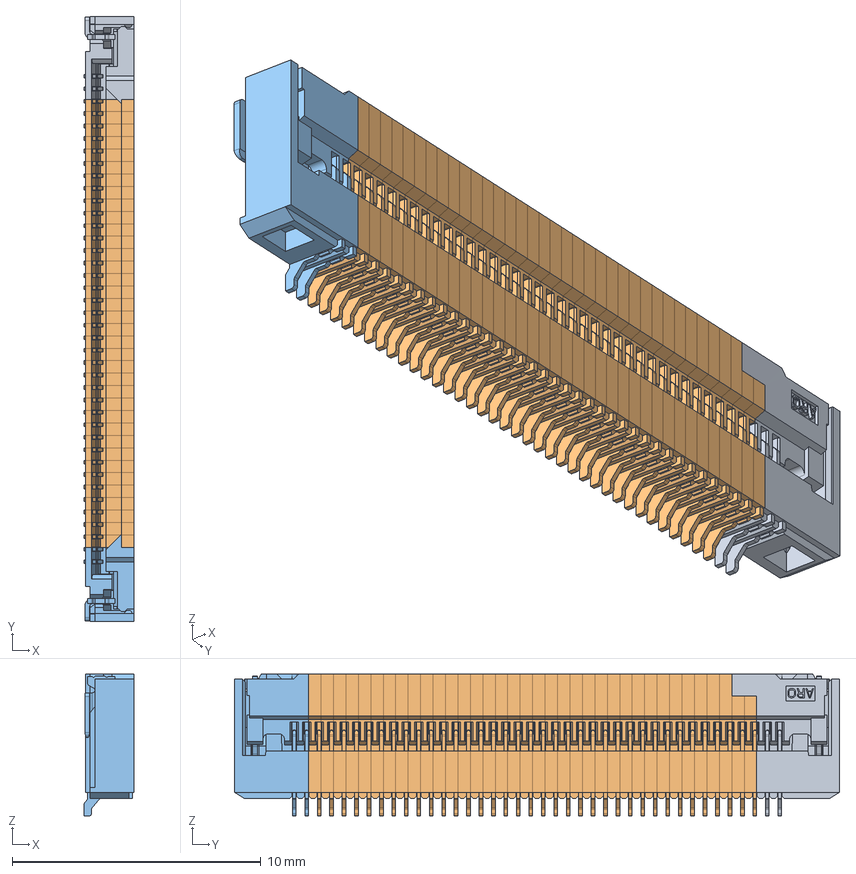
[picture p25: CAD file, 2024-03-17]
Fusion 360/Elektronik Libs/F305-1A7H1-11040-E100.stp
2.00 x 24.3 x 5.70 mm
F305_L
F305_M x 36
F305_R

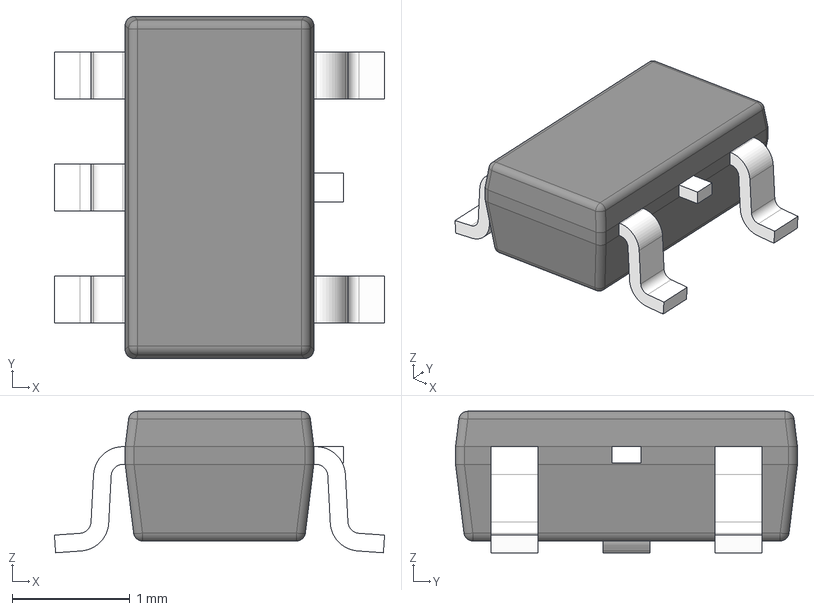
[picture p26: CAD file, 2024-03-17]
Fusion 360/Elektronik Libs/SN74LVC1G66DBVRE4.stp
2.80 x 2.90 x 1.20 mm
BODY-SOT
LEAD-SOT x 5
LEAD-DUMMY

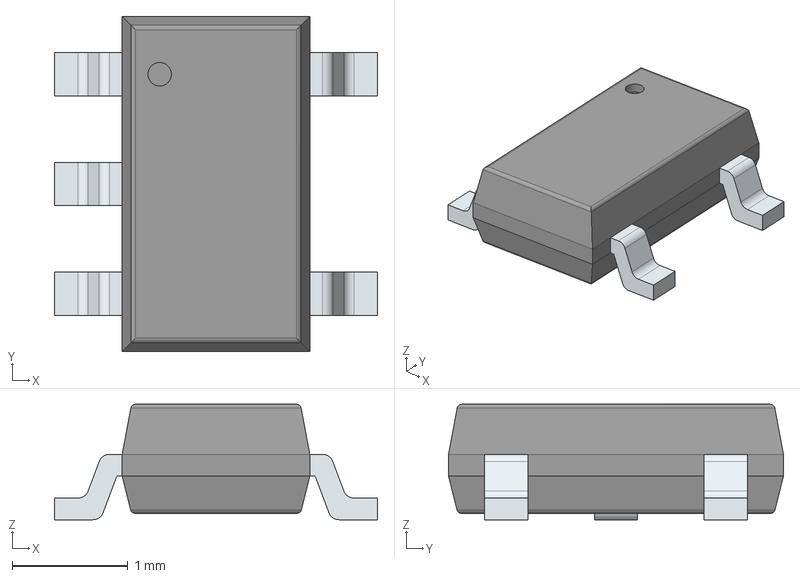
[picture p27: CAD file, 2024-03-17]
Fusion 360/Elektronik Libs/LT1818CS5#TRMPBF.stp
2.80 x 2.90 x 1.00 mm
PinsArrayL
PinsArrayR

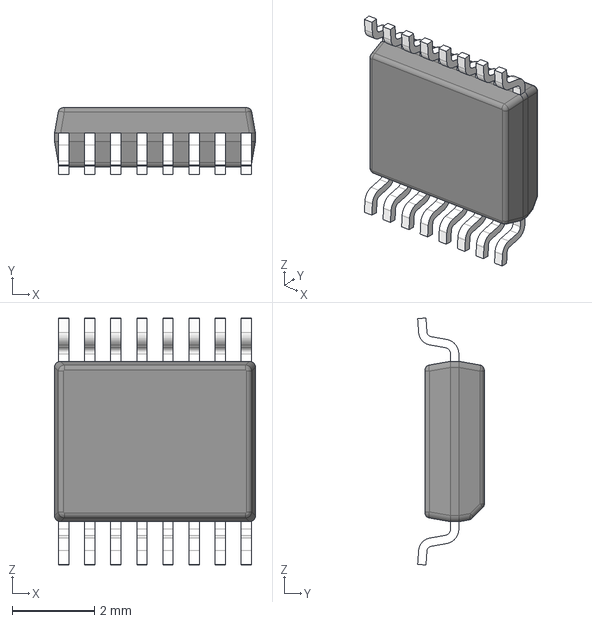
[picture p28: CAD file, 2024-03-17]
Fusion 360/Elektronik Libs/TCA9554DBQR.stp
4.90 x 1.63 x 6.02 mm
BODY-SO
LEAD-DBQ0016B x 16

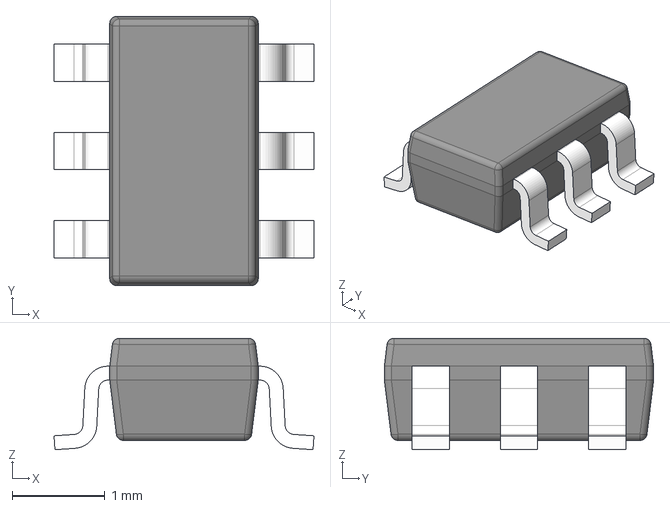
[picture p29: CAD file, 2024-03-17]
Fusion 360/Elektronik Libs/OPA300AIDBVT.stp
2.80 x 2.90 x 1.20 mm
BODY-SOT
LEAD-SOT x 6

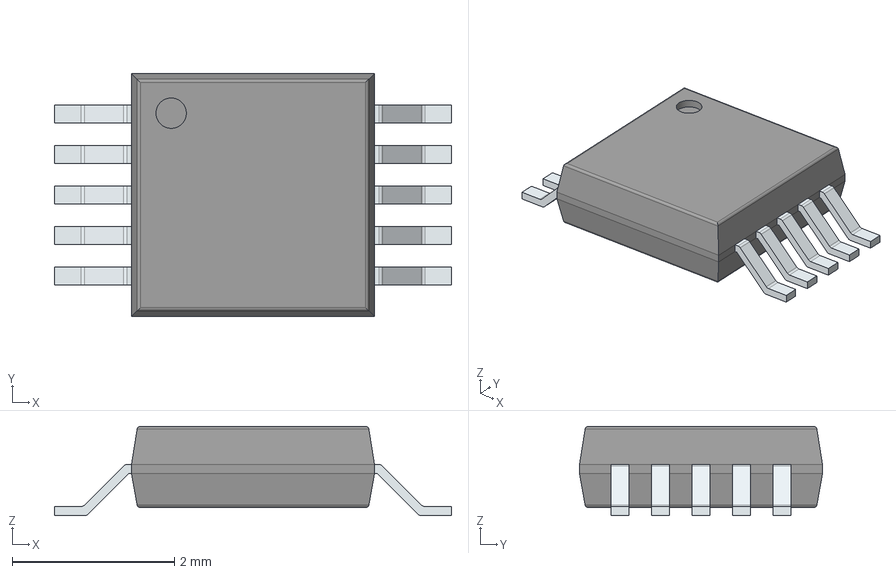
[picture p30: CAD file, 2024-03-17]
Fusion 360/Elektronik Libs/ADG621BRMZ.stp
4.90 x 3.00 x 1.10 mm
PinsArrayLR

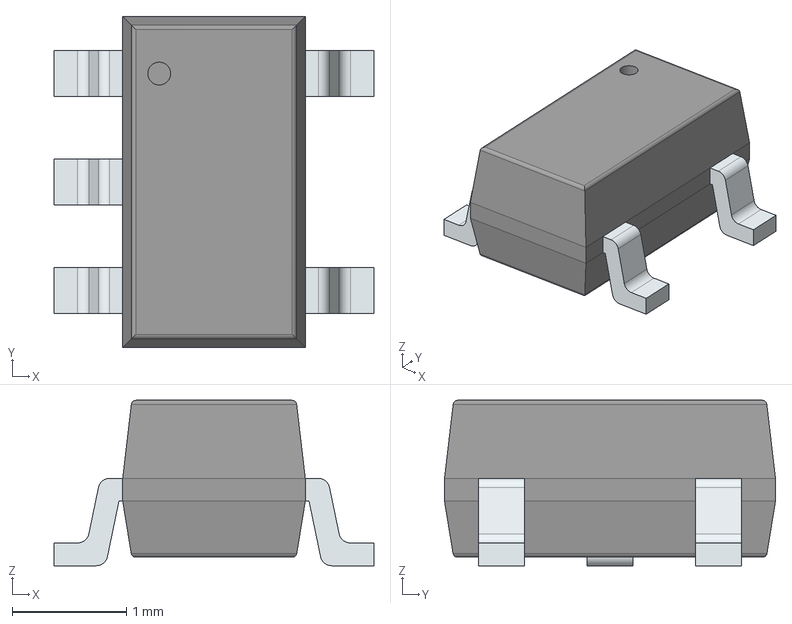
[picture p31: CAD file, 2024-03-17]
Fusion 360/Elektronik Libs/OPA820IDBVR.stp
2.80 x 2.90 x 1.45 mm
PinsArrayL
PinsArrayR

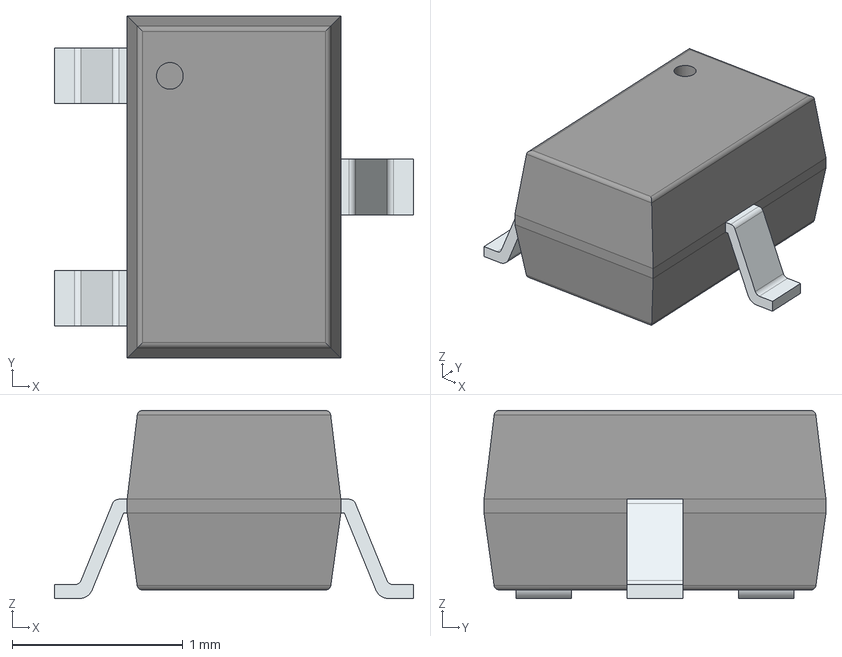
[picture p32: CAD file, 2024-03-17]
Fusion 360/Elektronik Libs/LM4040DELT-2.0.stp
2.10 x 2.00 x 1.10 mm
PinsArrayL
FilletPinR

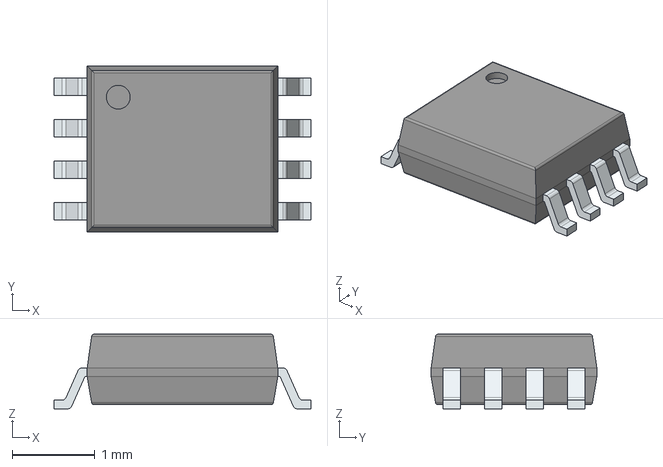
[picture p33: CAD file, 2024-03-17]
Fusion 360/Elektronik Libs/SN74LVC2G53DCUR.stp
3.10 x 2.00 x 0.9 mm
PinsArrayLR

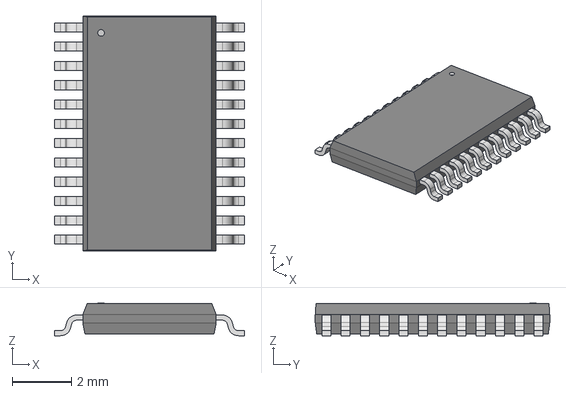
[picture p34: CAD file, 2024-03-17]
Fusion 360/Elektronik Libs/MTC24.step
6.40 x 7.90 x 1.09 mm

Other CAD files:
Fusion 360/Elektronik Libs/DBV6.step
Fusion 360/Elektronik Libs/LM27762DSST.stp
Fusion 360/Elektronik Libs/73137-5003.stp

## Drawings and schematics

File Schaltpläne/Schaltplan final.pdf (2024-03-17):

CH1

## RASPBERRY_PICOSMD

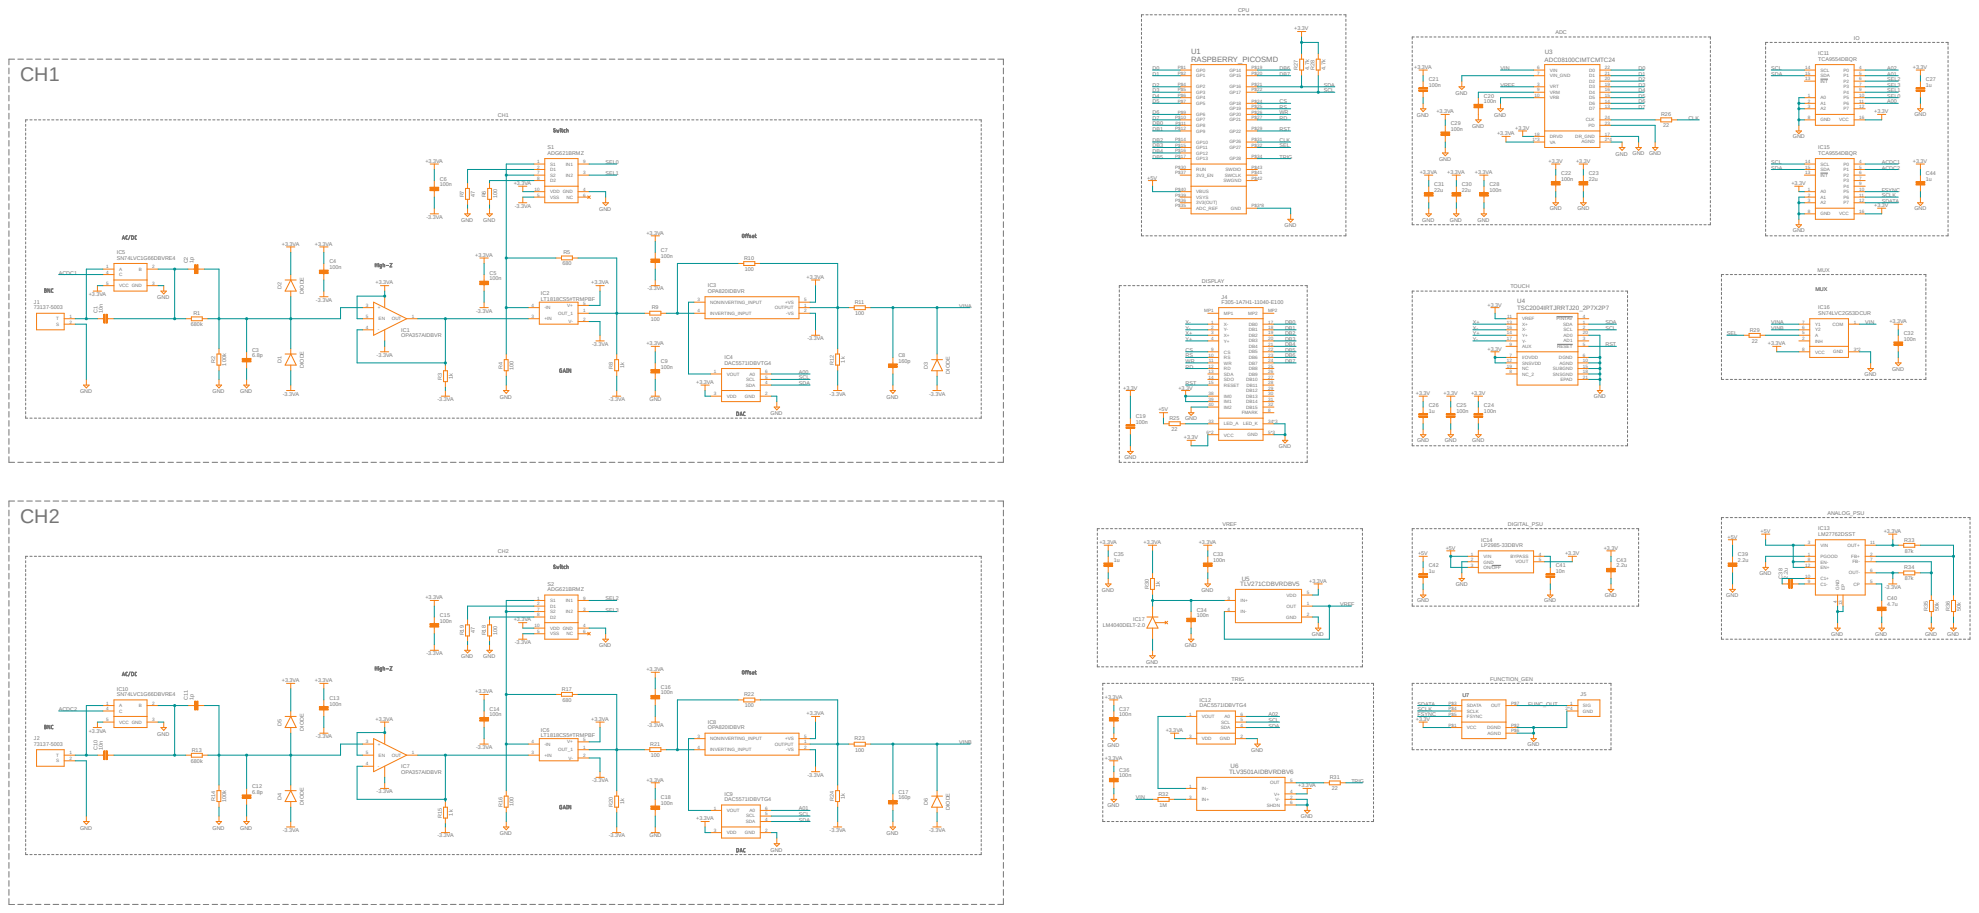
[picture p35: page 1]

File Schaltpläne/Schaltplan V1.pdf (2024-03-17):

CH1

## RASPBERRY_PICOSMD

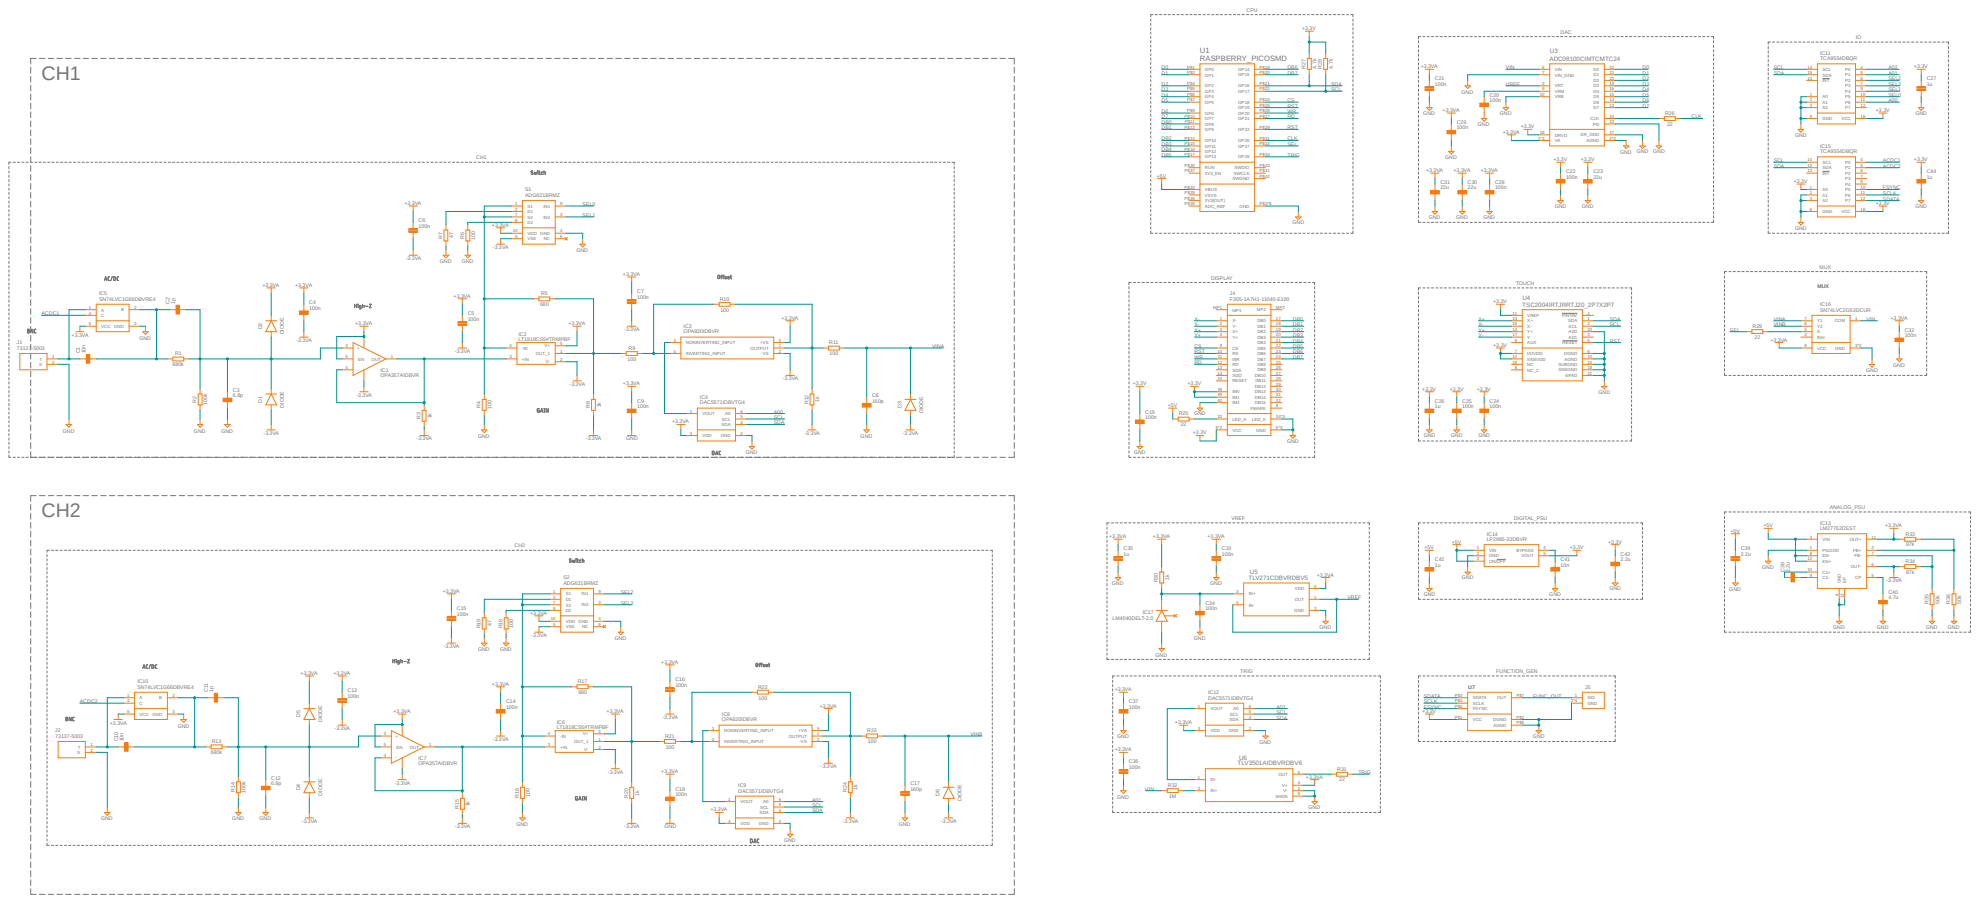
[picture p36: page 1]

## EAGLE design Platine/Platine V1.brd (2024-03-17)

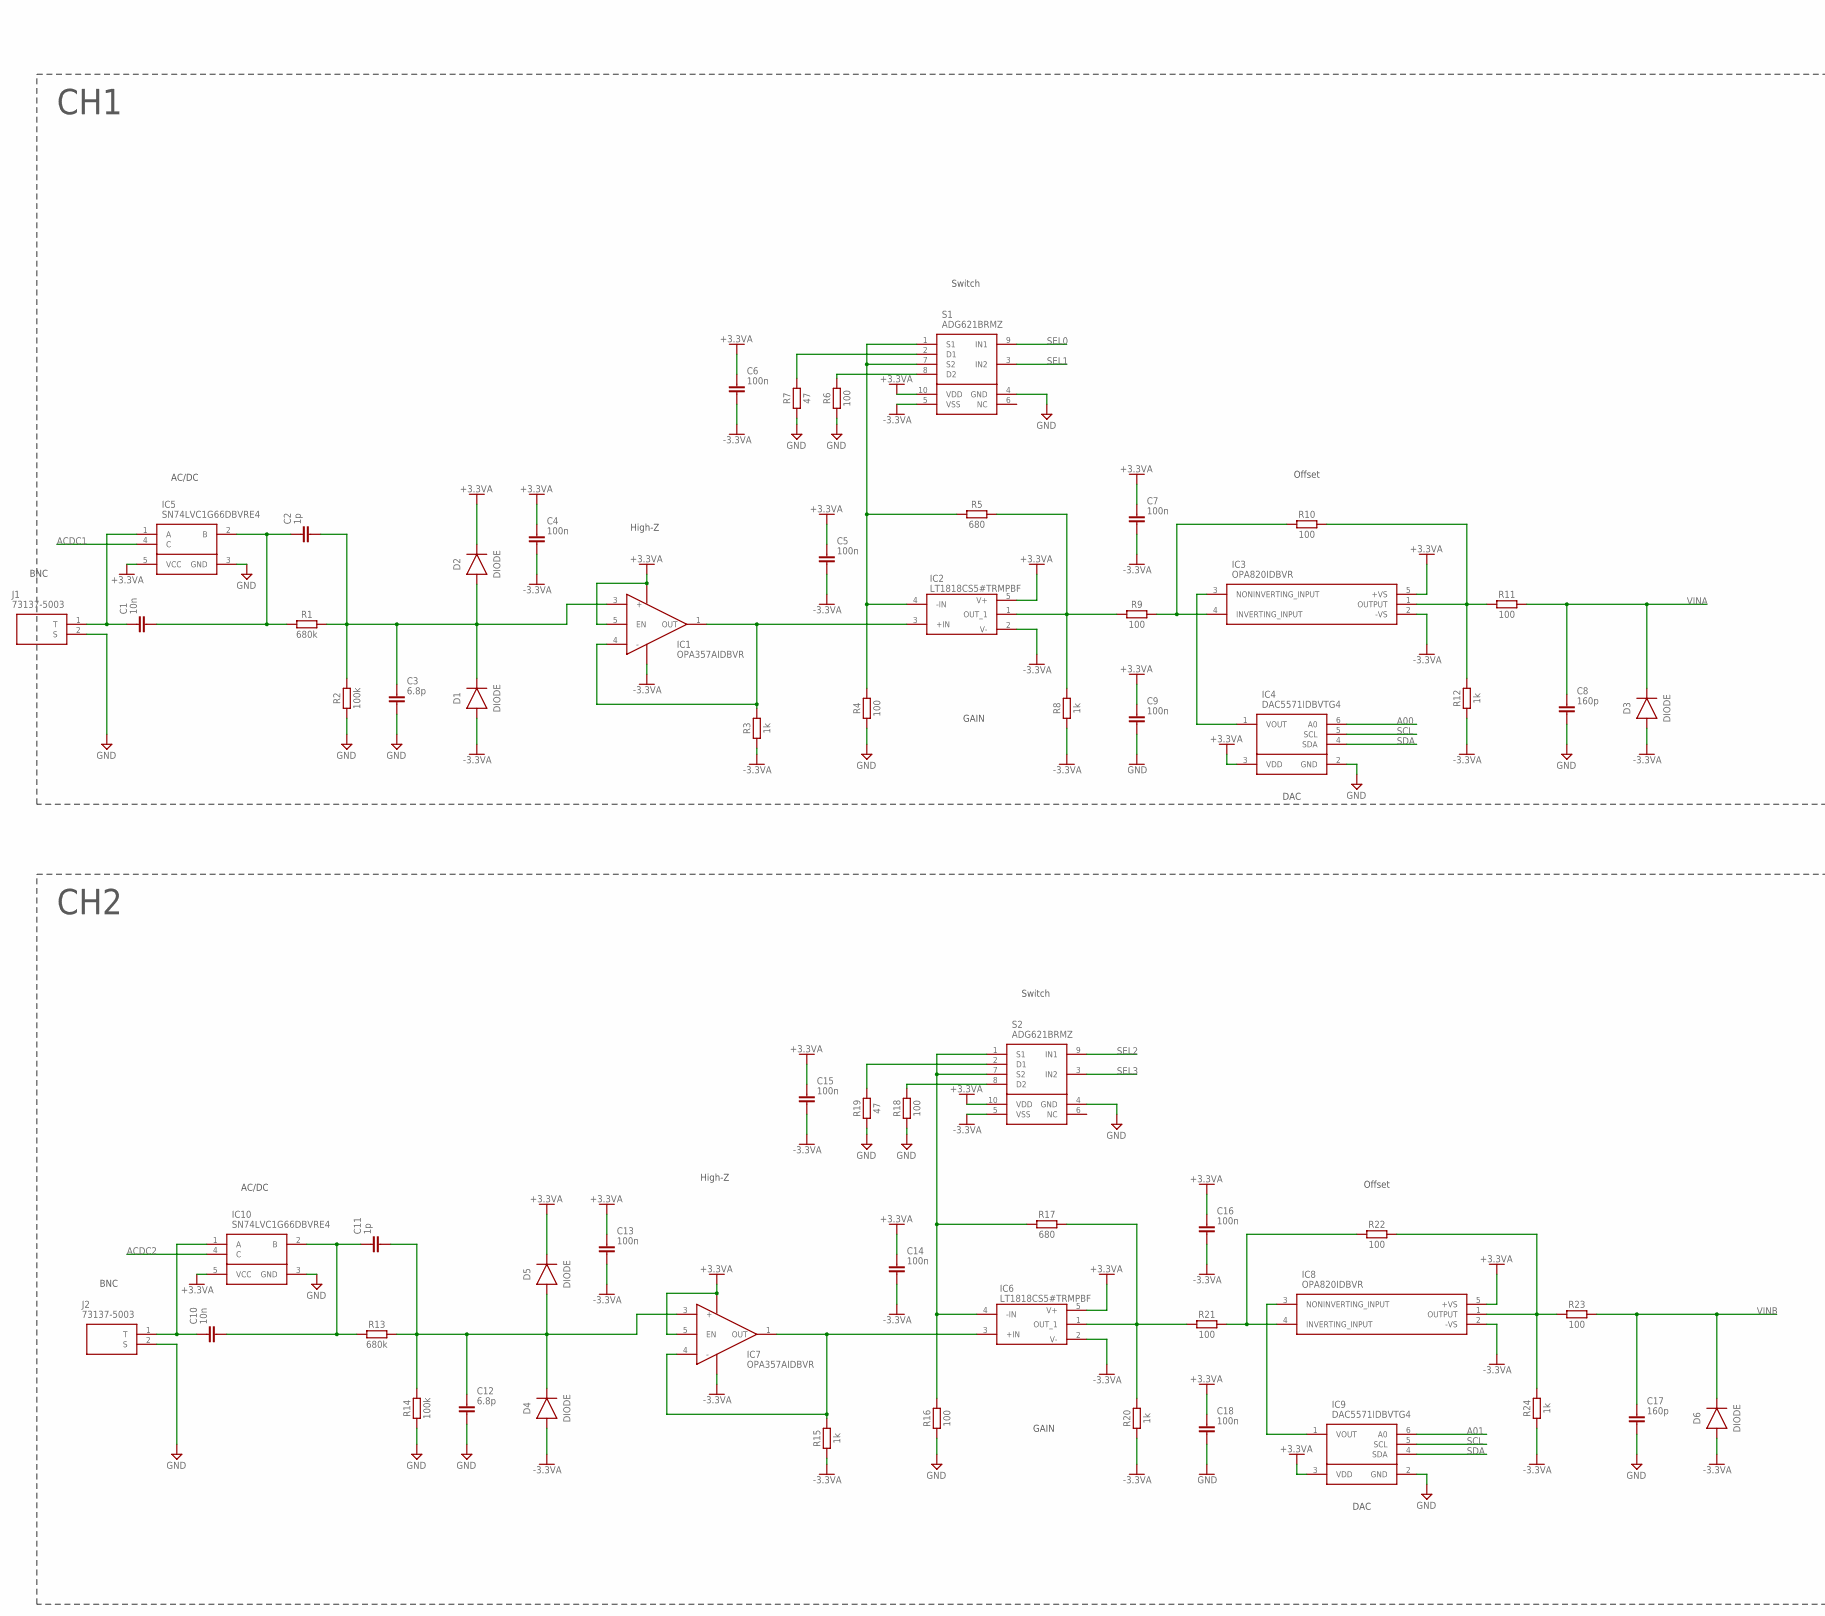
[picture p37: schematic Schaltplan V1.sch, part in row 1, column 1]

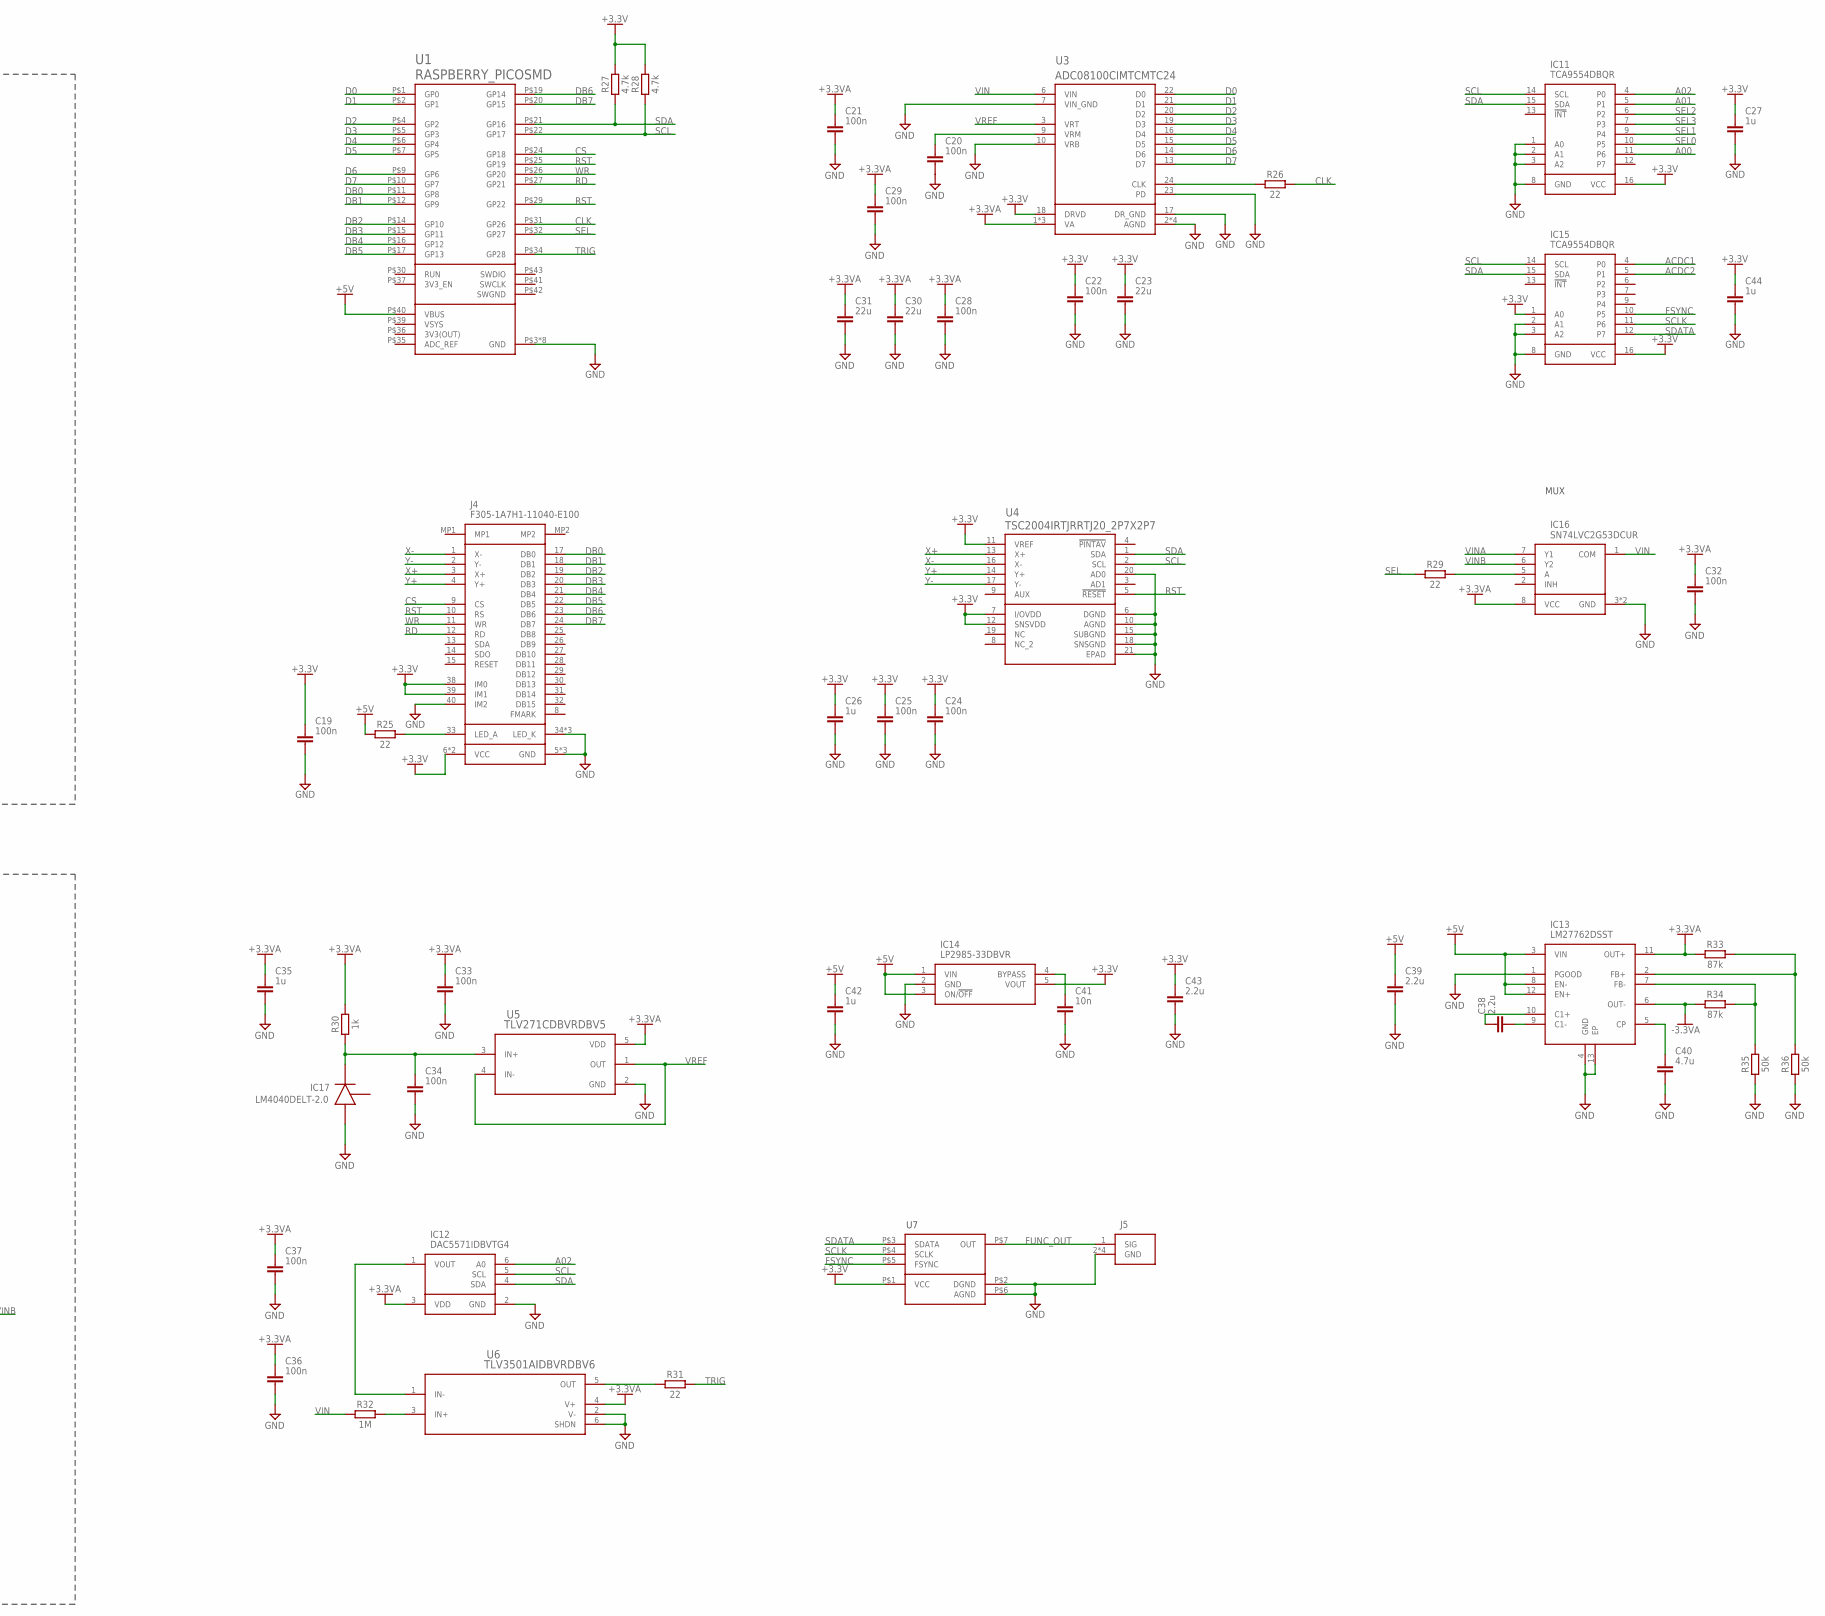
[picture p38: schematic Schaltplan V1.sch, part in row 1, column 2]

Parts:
C1, C10, C41: 10n; CAPC2012X110
C2, C11: 1p; CAPC2012X110
C3, C12: 6.8p; CAPC2012X110
C4, C5, C6, C7, C9, C13, C14, C15, C16, C18, C19, C20, C21, C22, C24, C25, C28, C29, C32, C33, C34, C36, C37: 100n; CAPC2012X110
C8, C17: 160p; CAPC2012X110
C23, C30, C31: 22u; CAPC2012X110
C26, C27, C35, C42, C44: 1u; CAPC2012X110
C38, C39, C43: 2.2u; CAPC2012X110
C40: 4.7u; CAPC2012X110
D1, D2, D3, D4, D5, D6: DIODE; SODFL2513X70
IC1, IC7: OPA357AIDBVR; SOT95P280X145-6N
IC2, IC6: LT1818CS5#TRMPBF; SOT95P280X100-5N
IC3, IC8: OPA820IDBVR; SOT95P280X145-5N
IC4, IC9, IC12: DAC5571IDBVTG4; SOT95P280X145-6N
IC5, IC10: SN74LVC1G66DBVRE4; SOT95P280X145-5N
IC11, IC15: TCA9554DBQR; SOP64P600X175-16N
IC13: LM27762DSST; SON50P200X300X80-13N
IC14: LP2985-33DBVR; SOT95P280X145-5N
IC16: SN74LVC2G53DCUR; SOP50P310X90-8N
IC17: LM4040DELT-2.0; SOT65P210X110-3N
J1, J2: 73137-5003; 731375003
J4: F305-1A7H1-11040-E100; F3051A7H111040E100
J5: PCB.SMAFRA.HT; PCBSMAFRAHT
R1, R13: 680k; RESC2012X65
R2, R14: 100k; RESC2012X65
R3, R8, R12, R15, R20, R24, R30: 1k; RESC2012X65
R4, R6, R9, R10, R11, R16, R18, R21, R22, R23: 100; RESC2012X65
R5, R17: 680; RESC2012X65
R7, R19: 47; RESC2012X65
R25, R26, R29, R31: 22; RESC2012X65
R27, R28: 4.7k; RESC2012X65
R32: 1M; RESC2012X65
R33, R34: 87k; RESC2012X65
R35, R36: 50k; RESC2012X65
S1, S2: ADG621BRMZ; SOP50P490X110-10N
U1: RASPBERRY_PICOSMD; PICO-PKG-SMD
U3: ADC08100CIMTCMTC24; MTC24
U4: TSC2004IRTJRRTJ20_2P7X2P7; RTJ20_2P7X2P7
U5: TLV271CDBVRDBV5; DBV5
U6: TLV3501AIDBVRDBV6; DBV6
U7: AD9833FUNCGEN

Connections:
3V3(OUT): U1.P$36 (3V3(OUT))
+3.3V: C19.1, C22.1, C23.1, C24.1, C25.1, C26.1, C27.1, C43.1, C44.1, IC11.16 (VCC), IC14.5 (VOUT), IC15.1 (A0), IC15.16 (VCC), J4.6 (VCC), J4.7 (VCC), J4.38 (IM0), J4.39 (IM1), R27.2, R28.2, U3.18 (DRVD), U4.7 (I/OVDD), U4.11 (VREF), U4.12 (SNSVDD), U7.P$1 (VCC)
+3.3VA: C4.1, C5.1, C6.1, C7.1, C9.1, C13.1, C14.1, C15.1, C16.1, C18.1, C21.1, C28.1, C29.1, C30.1, C31.1, C32.1, C33.1, C35.1, C36.1, C37.1, D2.1 (C), D5.1 (C), IC1.5 (EN), IC1.6 (V+), IC2.5 (V+), IC3.5 (+VS), IC4.3 (VDD), IC5.5 (VCC), IC6.5 (V+), IC7.5 (EN), IC7.6 (V+), IC8.5 (+VS), IC9.3 (VDD), IC10.5 (VCC), IC12.3 (VDD), IC13.11 (OUT+), IC16.8 (VCC), R30.2, R33.1, S1.10 (VDD), S2.10 (VDD), U3.1 (VA), U3.4 (VA), U3.12 (VA), U5.5 (VDD), U6.4 (V+)
+3.3VA1: C34.1, IC17.1 (K), R30.1, U5.3 (IN+)
+5V: C39.1, C42.1, IC13.3 (VIN), IC13.8 (EN-), IC13.12 (EN+), IC14.1 (VIN), IC14.3 (ON/!OFF), R25.1, U1.P$40 (VBUS)
-3.3VA: C4.2, C5.2, C6.2, C7.2, C13.2, C14.2, C15.2, C16.2, D1.2 (A), D3.2 (A), D4.2 (A), D6.2 (A), IC1.2 (V-), IC2.2 (V-), IC3.2 (-VS), IC6.2 (V-), IC7.2 (V-), IC8.2 (-VS), IC13.6 (OUT-), R3.1, R8.1, R12.1, R15.1, R20.1, R24.1, R34.1, S1.5 (VSS), S2.5 (VSS)
A00: IC4.6 (A0), IC11.11 (P6)
A01: IC9.6 (A0), IC11.5 (P1)
A02: IC11.4 (P0), IC12.6 (A0)
ACDC1: IC5.4 (C), IC15.4 (P0)
ACDC2: IC10.4 (C), IC15.5 (P1)
CLK: R26.2, U1.P$31 (GP26)
CS: J4.9 (CS), U1.P$24 (GP18)
D0: U1.P$1 (GP0), U3.22 (D0)
D1: U1.P$2 (GP1), U3.21 (D1)
D2: U1.P$4 (GP2), U3.20 (D2)
D3: U1.P$5 (GP3), U3.19 (D3)
D4: U1.P$6 (GP4), U3.16 (D4)
D5: U1.P$7 (GP5), U3.15 (D5)
D6: U1.P$9 (GP6), U3.14 (D6)
D7: U1.P$10 (GP7), U3.13 (D7)
DB0: J4.17 (DB0), U1.P$11 (GP8)
DB1: J4.18 (DB1), U1.P$12 (GP9)
DB2: J4.19 (DB2), U1.P$14 (GP10)
DB3: J4.20 (DB3), U1.P$15 (GP11)
DB4: J4.21 (DB4), U1.P$16 (GP12)
DB5: J4.22 (DB5), U1.P$17 (GP13)
DB6: J4.23 (DB6), U1.P$19 (GP14)
DB7: J4.24 (DB7), U1.P$20 (GP15)
FSYNC: IC15.10 (P5), U7.P$5 (FSYNC)
FUNC_OUT: J5.1 (SIG), U7.P$7 (OUT)
GND: C3.2, C8.2, C9.2, C12.2, C17.2, C18.2, C19.2, C20.2, C21.2, C22.2, C23.2, C24.2, C25.2, C26.2, C27.2, C28.2, C29.2, C30.2, C31.2, C32.2, C33.2, C34.2, C35.2, C36.2, C37.2, C39.2, C40.2, C41.2, C42.2, C43.2, C44.2, IC4.2 (GND), IC5.3 (GND), IC9.2 (GND), IC10.3 (GND), IC11.1 (A0), IC11.2 (A1), IC11.3 (A2), IC11.8 (GND), IC12.2 (GND), IC13.1 (PGOOD), IC13.4 (GND), IC13.13 (EP), IC14.2 (GND), IC15.2 (A1), IC15.3 (A2), IC15.8 (GND), IC16.3 (GND), IC16.4 (GND), IC17.2 (A), J1.2 (S), J2.2 (S), J4.5 (GND), J4.16 (GND), J4.34 (LED_K), J4.35 (LED_K), J4.36 (LED_K), J4.37 (GND), J4.40 (IM2), J5.2 (GND), J5.3 (GND), J5.4 (GND), J5.5 (GND), R2.1, R4.1, R6.1, R7.1, R14.1, R16.1, R18.1, R19.1, R35.1, R36.1, S1.4 (GND), S2.4 (GND), U1.P$3 (GND), U1.P$8 (GND), U1.P$13 (GND), U1.P$18 (GND), U1.P$23 (GND), U1.P$28 (GND), U1.P$33 (GND), U1.P$38 (GND), U3.2 (AGND), U3.5 (AGND), U3.7 (VIN_GND), U3.8 (AGND), U3.10 (VRB), U3.11 (AGND), U3.17 (DR_GND), U3.23 (PD), U4.6 (DGND), U4.10 (AGND), U4.15 (SUBGND), U4.18 (SNSGND), U4.20 (AD0), U4.21 (EPAD), U5.2 (GND), U6.2 (V-), U6.6 (SHDN), U7.P$2 (DGND), U7.P$6 (AGND)
unnamed: C1.1, IC5.1 (A), J1.1 (T)
unnamed: C1.2, C2.1, IC5.2 (B), R1.1
unnamed: C2.2, C3.1, D1.1 (C), D2.2 (A), IC1.3 (+), R1.2, R2.2
unnamed: R7.2, S1.2 (D1)
unnamed: IC2.4 (-IN), R4.2, R5.1, S1.1 (S1), S1.7 (S2)
unnamed: IC2.1 (OUT_1), R5.2, R8.2, R9.1
unnamed: IC1.1 (OUT), IC1.4 (-), IC2.3 (+IN), R3.2
unnamed: R6.2, S1.8 (D2)
unnamed: IC3.4 (INVERTING_INPUT), R9.2, R10.1
unnamed: IC3.1 (OUTPUT), R10.2, R11.1, R12.2
unnamed: IC3.3 (NONINVERTING_INPUT), IC4.1 (VOUT)
unnamed: C10.1, IC10.1 (A), J2.1 (T)
unnamed: C10.2, C11.1, IC10.2 (B), R13.1
unnamed: C11.2, C12.1, D4.1 (C), D5.2 (A), IC7.3 (+), R13.2, R14.2
unnamed: IC6.4 (-IN), R16.2, R17.1, S2.1 (S1), S2.7 (S2)
unnamed: IC6.1 (OUT_1), R17.2, R20.2, R21.1
unnamed: IC6.3 (+IN), IC7.1 (OUT), IC7.4 (-), R15.2
unnamed: R19.2, S2.2 (D1)
unnamed: R18.2, S2.8 (D2)
unnamed: IC8.4 (INVERTING_INPUT), R21.2, R22.1
unnamed: IC8.1 (OUTPUT), R22.2, R23.1, R24.2
unnamed: IC8.3 (NONINVERTING_INPUT), IC9.1 (VOUT)
unnamed: R31.1, U6.5 (OUT)
unnamed: R32.2, U6.3 (IN+)
unnamed: IC12.1 (VOUT), U6.1 (IN-)
unnamed: C20.1, U3.9 (VRM)
unnamed: J4.33 (LED_A), R25.2
unnamed: C40.1, IC13.5 (CP)
unnamed: IC13.2 (FB+), R33.2, R36.2
unnamed: C41.1, IC14.4 (BYPASS)
unnamed: IC13.7 (FB-), R34.2, R35.2
unnamed: C38.1, IC13.10 (C1+)
unnamed: C38.2, IC13.9 (C1-)
unnamed: IC16.5 (A), R29.2
unnamed: R26.1, U3.24 (CLK)
RD: J4.12 (RD), U1.P$27 (GP21)
SCL: IC4.5 (SCL), IC9.5 (SCL), IC11.14 (SCL), IC12.5 (SCL), IC15.14 (SCL), R28.1, U1.P$22 (GP17), U4.2 (SCL)
SCLK: IC15.11 (P6), U7.P$4 (SCLK)
SDA: IC4.4 (SDA), IC9.4 (SDA), IC11.15 (SDA), IC12.4 (SDA), IC15.15 (SDA), R27.1, U1.P$21 (GP16), U4.1 (SDA)
SDATA: IC15.12 (P7), U7.P$3 (SDATA)
SEL: R29.1, U1.P$32 (GP27)
SEL0: IC11.10 (P5), S1.9 (IN1)
SEL1: IC11.9 (P4), S1.3 (IN2)
SEL2: IC11.6 (P2), S2.9 (IN1)
SEL3: IC11.7 (P3), S2.3 (IN2)
SWGND: U1.P$42 (SWGND)
TRIG: R31.2, U1.P$34 (GP28)
VIN: IC16.1 (COM), R32.1, U3.6 (VIN)
VINA: C8.1, D3.1 (C), IC16.7 (Y1), R11.2
VINB: C17.1, D6.1 (C), IC16.6 (Y2), R23.2
VREF: U3.3 (VRT), U5.1 (OUT), U5.4 (IN-)
VSYS: U1.P$39 (VSYS)
WR: J4.11 (WR), U1.P$26 (GP20)
X+: J4.3 (X+), U4.13 (X+)
X-: J4.1 (X-), U4.16 (X-)
Y+: J4.4 (Y+), U4.14 (Y+)
Y-: J4.2 (Y-), U4.17 (Y-)

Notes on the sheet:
CH1
BNC
AC/DC
High-Z
Switch
GAIN
Offset
DAC
CH2
MUX

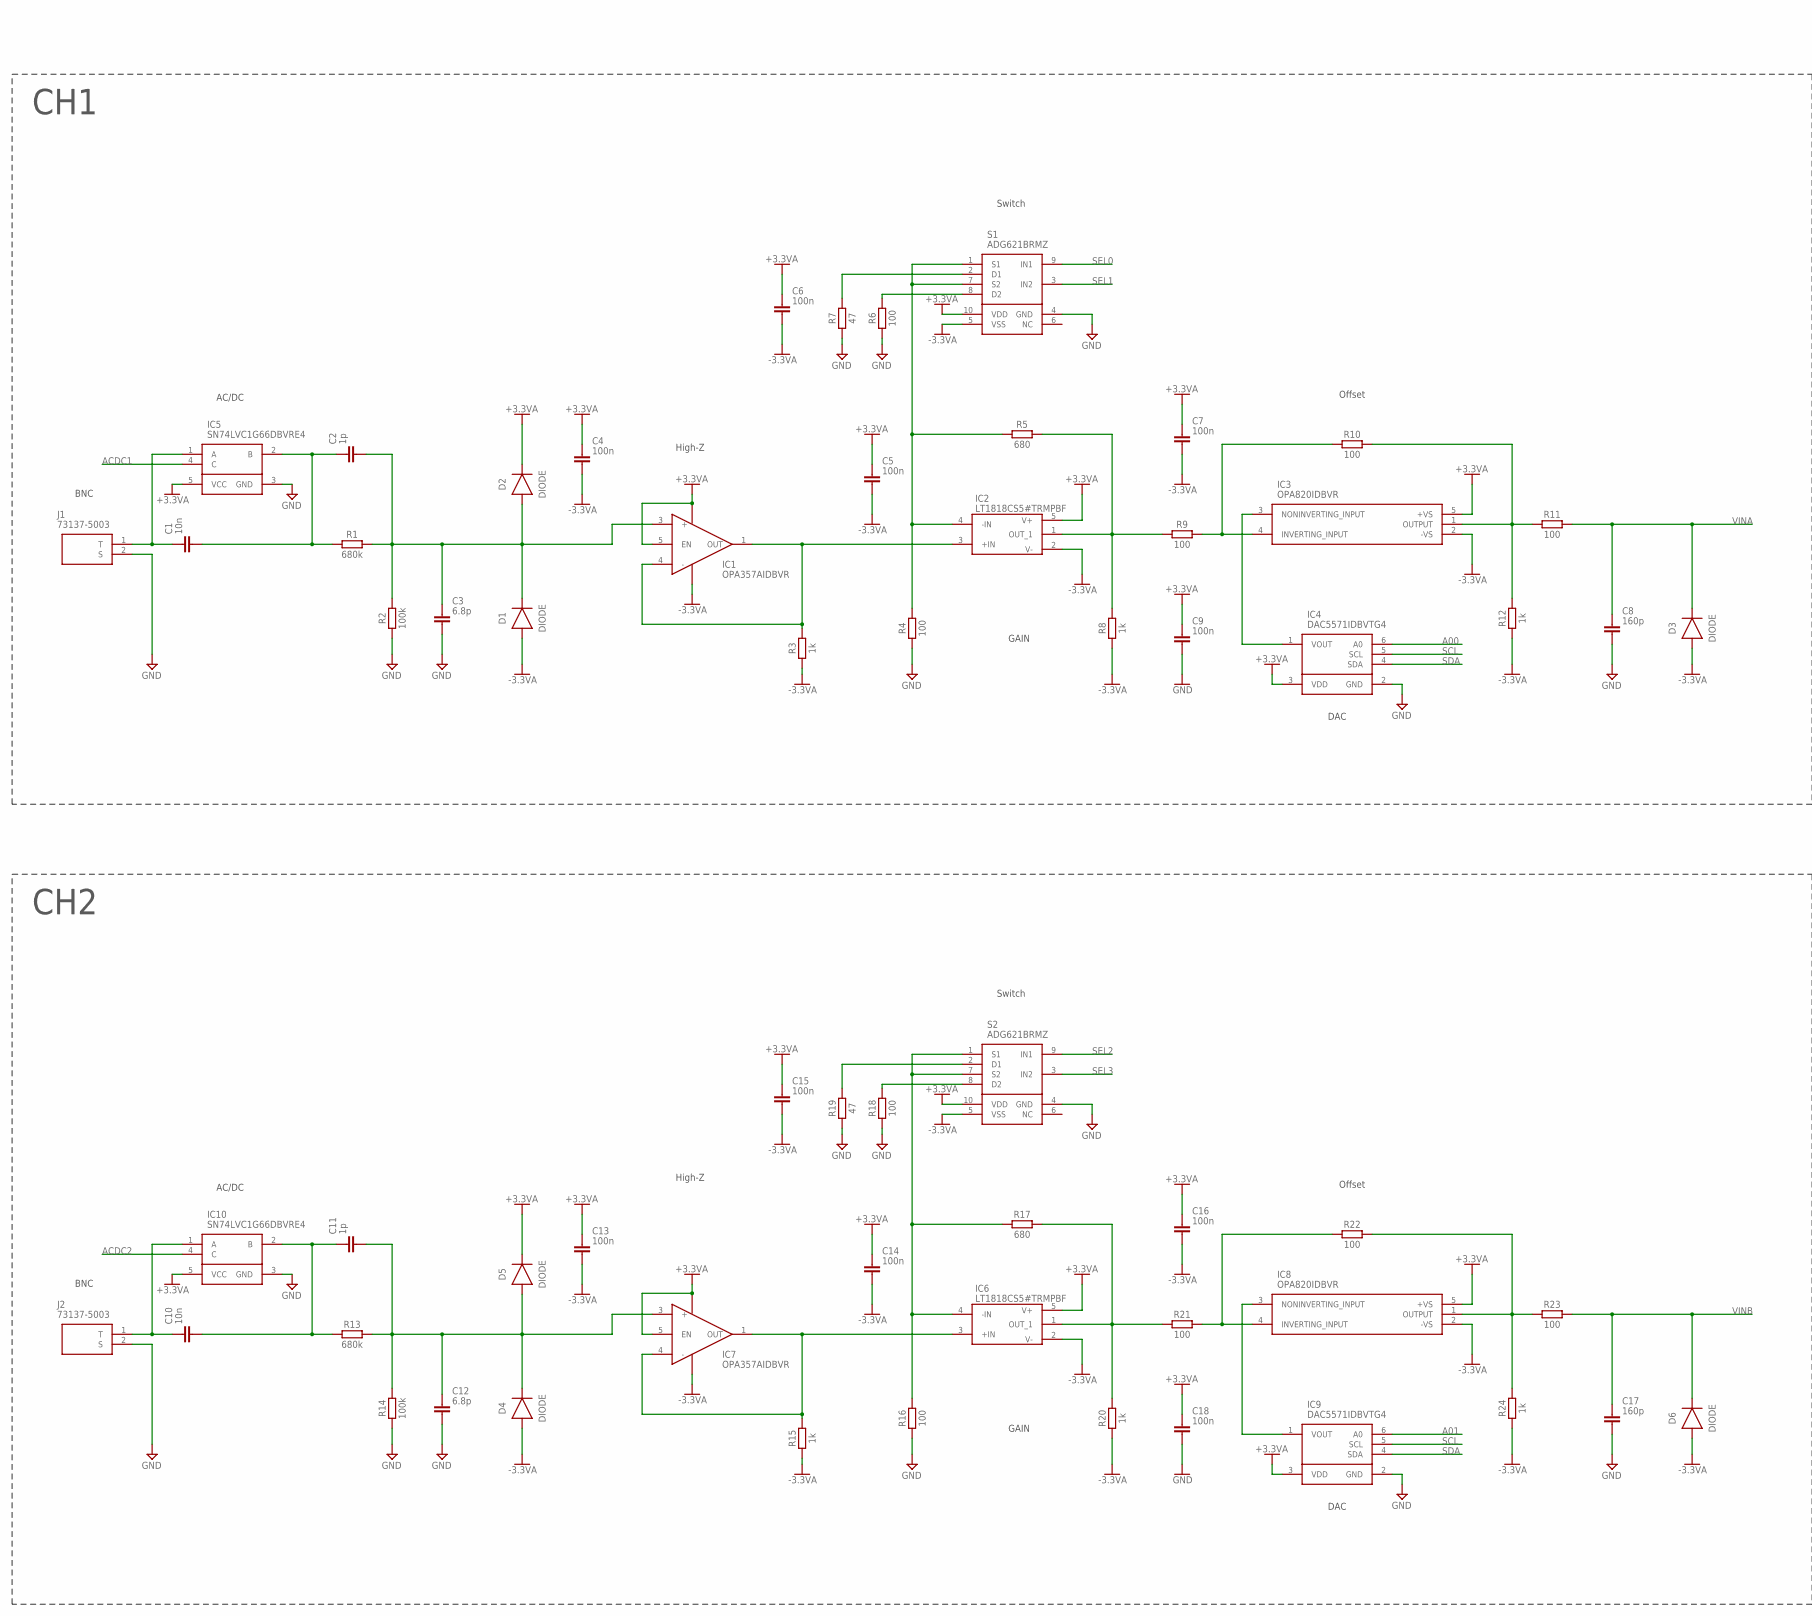
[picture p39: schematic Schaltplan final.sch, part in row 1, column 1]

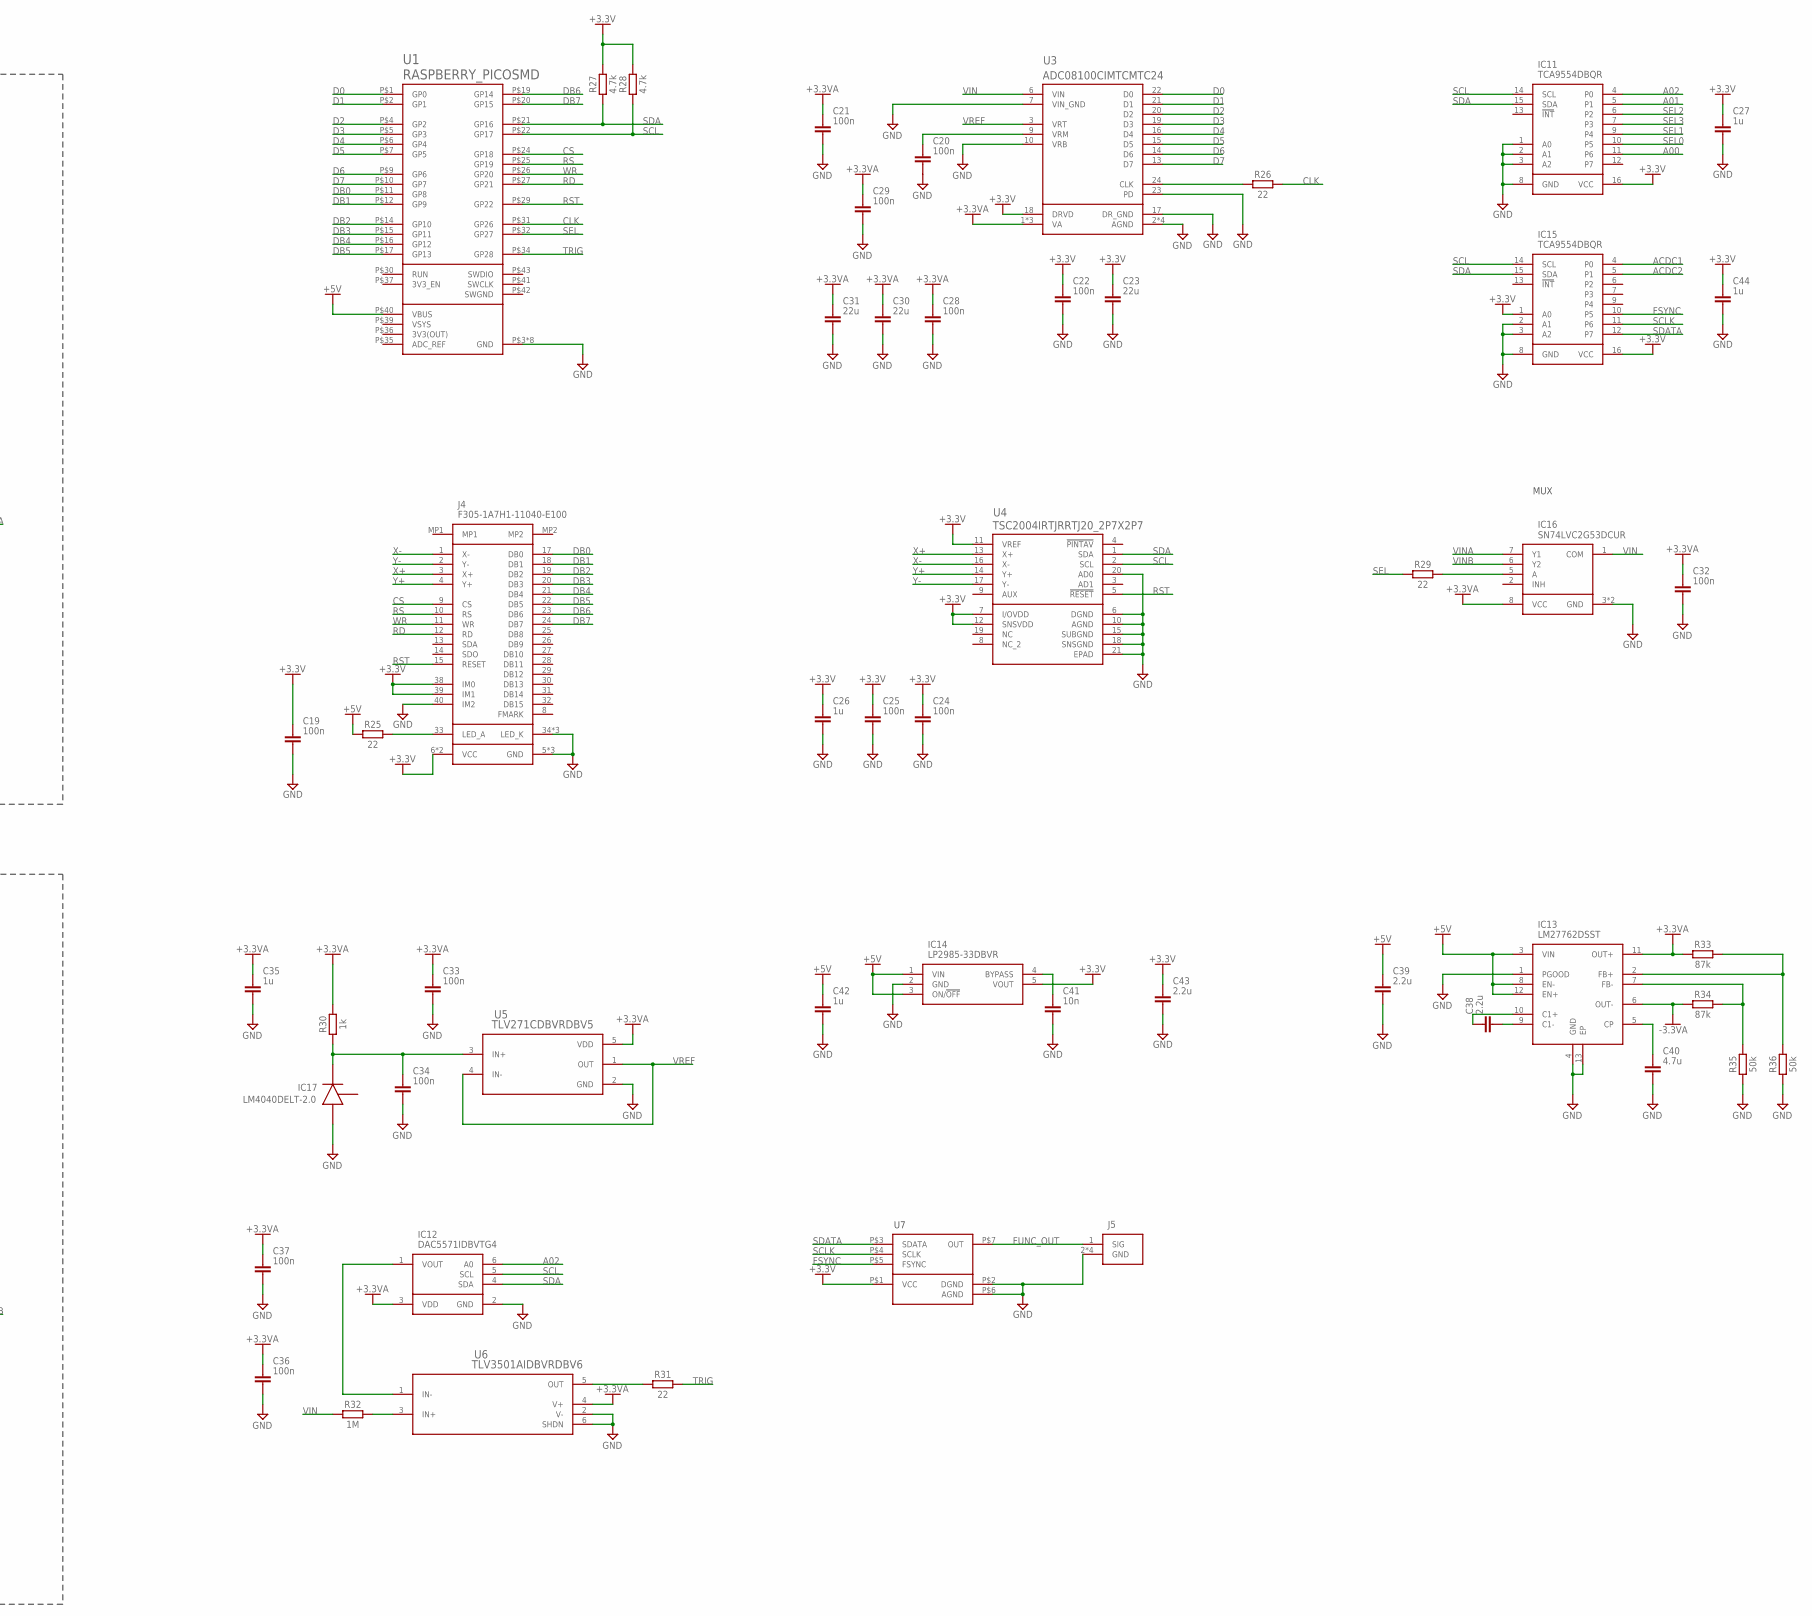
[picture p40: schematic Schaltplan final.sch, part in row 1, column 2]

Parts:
C1, C10, C41: 10n; CAPC2012X110
C2, C11: 1p; CAPC2012X110
C3, C12: 6.8p; CAPC2012X110
C4, C5, C6, C7, C9, C13, C14, C15, C16, C18, C19, C20, C21, C22, C24, C25, C28, C29, C32, C33, C34, C36, C37: 100n; CAPC2012X110
C8, C17: 160p; CAPC2012X110
C23, C30, C31: 22u; CAPC2012X110
C26, C27, C35, C42, C44: 1u; CAPC2012X110
C38, C39, C43: 2.2u; CAPC2012X110
C40: 4.7u; CAPC2012X110
D1, D2, D3, D4, D5, D6: DIODE; SODFL2513X70
IC1, IC7: OPA357AIDBVR; SOT95P280X145-6N
IC2, IC6: LT1818CS5#TRMPBF; SOT95P280X100-5N
IC3, IC8: OPA820IDBVR; SOT95P280X145-5N
IC4, IC9, IC12: DAC5571IDBVTG4; SOT95P280X145-6N
IC5, IC10: SN74LVC1G66DBVRE4; SOT95P280X145-5N
IC11, IC15: TCA9554DBQR; SOP64P600X175-16N
IC13: LM27762DSST; SON50P200X300X80-13N
IC14: LP2985-33DBVR; SOT95P280X145-5N
IC16: SN74LVC2G53DCUR; SOP50P310X90-8N
IC17: LM4040DELT-2.0; SOT65P210X110-3N
J1, J2: 73137-5003; 731375003
J4: F305-1A7H1-11040-E100; F3051A7H111040E100
J5: PCB.SMAFRA.HT; PCBSMAFRAHT
R1, R13: 680k; RESC2012X65
R2, R14: 100k; RESC2012X65
R3, R8, R12, R15, R20, R24, R30: 1k; RESC2012X65
R4, R6, R9, R10, R11, R16, R18, R21, R22, R23: 100; RESC2012X65
R5, R17: 680; RESC2012X65
R7, R19: 47; RESC2012X65
R25, R26, R29, R31: 22; RESC2012X65
R27, R28: 4.7k; RESC2012X65
R32: 1M; RESC2012X65
R33, R34: 87k; RESC2012X65
R35, R36: 50k; RESC2012X65
S1, S2: ADG621BRMZ; SOP50P490X110-10N
U1: RASPBERRY_PICOSMD; PICO-PKG-SMD
U3: ADC08100CIMTCMTC24; MTC24
U4: TSC2004IRTJRRTJ20_2P7X2P7; RTJ20_2P7X2P7
U5: TLV271CDBVRDBV5; DBV5
U6: TLV3501AIDBVRDBV6; DBV6
U7: AD9833FUNCGEN

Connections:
3V3(OUT): U1.P$36 (3V3(OUT))
+3.3V: C19.1, C22.1, C23.1, C24.1, C25.1, C26.1, C27.1, C43.1, C44.1, IC11.16 (VCC), IC14.5 (VOUT), IC15.1 (A0), IC15.16 (VCC), J4.6 (VCC), J4.7 (VCC), J4.38 (IM0), J4.39 (IM1), R27.2, R28.2, U3.18 (DRVD), U4.7 (I/OVDD), U4.11 (VREF), U4.12 (SNSVDD), U7.P$1 (VCC)
+3.3VA: C4.1, C5.1, C6.1, C7.1, C9.1, C13.1, C14.1, C15.1, C16.1, C18.1, C21.1, C28.1, C29.1, C30.1, C31.1, C32.1, C33.1, C35.1, C36.1, C37.1, D2.1 (C), D5.1 (C), IC1.5 (EN), IC1.6 (V+), IC2.5 (V+), IC3.5 (+VS), IC4.3 (VDD), IC5.5 (VCC), IC6.5 (V+), IC7.5 (EN), IC7.6 (V+), IC8.5 (+VS), IC9.3 (VDD), IC10.5 (VCC), IC12.3 (VDD), IC13.11 (OUT+), IC16.8 (VCC), R30.2, R33.1, S1.10 (VDD), S2.10 (VDD), U3.1 (VA), U3.4 (VA), U3.12 (VA), U5.5 (VDD), U6.4 (V+)
+3.3VA1: C34.1, IC17.1 (K), R30.1, U5.3 (IN+)
+5V: C39.1, C42.1, IC13.3 (VIN), IC13.8 (EN-), IC13.12 (EN+), IC14.1 (VIN), IC14.3 (ON/!OFF), R25.1, U1.P$40 (VBUS)
-3.3VA: C4.2, C5.2, C6.2, C7.2, C13.2, C14.2, C15.2, C16.2, D1.2 (A), D3.2 (A), D4.2 (A), D6.2 (A), IC1.2 (V-), IC2.2 (V-), IC3.2 (-VS), IC6.2 (V-), IC7.2 (V-), IC8.2 (-VS), IC13.6 (OUT-), R3.1, R8.1, R12.1, R15.1, R20.1, R24.1, R34.1, S1.5 (VSS), S2.5 (VSS)
A00: IC4.6 (A0), IC11.11 (P6)
A01: IC9.6 (A0), IC11.5 (P1)
A02: IC11.4 (P0), IC12.6 (A0)
ACDC1: IC5.4 (C), IC15.4 (P0)
ACDC2: IC10.4 (C), IC15.5 (P1)
CLK: R26.2, U1.P$31 (GP26)
CS: J4.9 (CS), U1.P$24 (GP18)
D0: U1.P$1 (GP0), U3.22 (D0)
D1: U1.P$2 (GP1), U3.21 (D1)
D2: U1.P$4 (GP2), U3.20 (D2)
D3: U1.P$5 (GP3), U3.19 (D3)
D4: U1.P$6 (GP4), U3.16 (D4)
D5: U1.P$7 (GP5), U3.15 (D5)
D6: U1.P$9 (GP6), U3.14 (D6)
D7: U1.P$10 (GP7), U3.13 (D7)
DB0: J4.17 (DB0), U1.P$11 (GP8)
DB1: J4.18 (DB1), U1.P$12 (GP9)
DB2: J4.19 (DB2), U1.P$14 (GP10)
DB3: J4.20 (DB3), U1.P$15 (GP11)
DB4: J4.21 (DB4), U1.P$16 (GP12)
DB5: J4.22 (DB5), U1.P$17 (GP13)
DB6: J4.23 (DB6), U1.P$19 (GP14)
DB7: J4.24 (DB7), U1.P$20 (GP15)
FSYNC: IC15.10 (P5), U7.P$5 (FSYNC)
FUNC_OUT: J5.1 (SIG), U7.P$7 (OUT)
GND: C3.2, C8.2, C9.2, C12.2, C17.2, C18.2, C19.2, C20.2, C21.2, C22.2, C23.2, C24.2, C25.2, C26.2, C27.2, C28.2, C29.2, C30.2, C31.2, C32.2, C33.2, C34.2, C35.2, C36.2, C37.2, C39.2, C40.2, C41.2, C42.2, C43.2, C44.2, IC4.2 (GND), IC5.3 (GND), IC9.2 (GND), IC10.3 (GND), IC11.1 (A0), IC11.2 (A1), IC11.3 (A2), IC11.8 (GND), IC12.2 (GND), IC13.1 (PGOOD), IC13.4 (GND), IC13.13 (EP), IC14.2 (GND), IC15.2 (A1), IC15.3 (A2), IC15.8 (GND), IC16.3 (GND), IC16.4 (GND), IC17.2 (A), J1.2 (S), J2.2 (S), J4.5 (GND), J4.16 (GND), J4.34 (LED_K), J4.35 (LED_K), J4.36 (LED_K), J4.37 (GND), J4.40 (IM2), J5.2 (GND), J5.3 (GND), J5.4 (GND), J5.5 (GND), R2.1, R4.1, R6.1, R7.1, R14.1, R16.1, R18.1, R19.1, R35.1, R36.1, S1.4 (GND), S2.4 (GND), U1.P$3 (GND), U1.P$8 (GND), U1.P$13 (GND), U1.P$18 (GND), U1.P$23 (GND), U1.P$28 (GND), U1.P$33 (GND), U1.P$38 (GND), U3.2 (AGND), U3.5 (AGND), U3.7 (VIN_GND), U3.8 (AGND), U3.10 (VRB), U3.11 (AGND), U3.17 (DR_GND), U3.23 (PD), U4.6 (DGND), U4.10 (AGND), U4.15 (SUBGND), U4.18 (SNSGND), U4.20 (AD0), U4.21 (EPAD), U5.2 (GND), U6.2 (V-), U6.6 (SHDN), U7.P$2 (DGND), U7.P$6 (AGND)
unnamed: C1.1, IC5.1 (A), J1.1 (T)
unnamed: C1.2, C2.1, IC5.2 (B), R1.1
unnamed: C2.2, C3.1, D1.1 (C), D2.2 (A), IC1.3 (+), R1.2, R2.2
unnamed: R7.2, S1.2 (D1)
unnamed: IC2.4 (-IN), R4.2, R5.1, S1.1 (S1), S1.7 (S2)
unnamed: IC2.1 (OUT_1), R5.2, R8.2, R9.1
unnamed: IC1.1 (OUT), IC1.4 (-), IC2.3 (+IN), R3.2
unnamed: R6.2, S1.8 (D2)
unnamed: IC3.4 (INVERTING_INPUT), R9.2, R10.1
unnamed: IC3.1 (OUTPUT), R10.2, R11.1, R12.2
unnamed: IC3.3 (NONINVERTING_INPUT), IC4.1 (VOUT)
unnamed: C10.1, IC10.1 (A), J2.1 (T)
unnamed: C10.2, C11.1, IC10.2 (B), R13.1
unnamed: C11.2, C12.1, D4.1 (C), D5.2 (A), IC7.3 (+), R13.2, R14.2
unnamed: IC6.4 (-IN), R16.2, R17.1, S2.1 (S1), S2.7 (S2)
unnamed: IC6.1 (OUT_1), R17.2, R20.2, R21.1
unnamed: IC6.3 (+IN), IC7.1 (OUT), IC7.4 (-), R15.2
unnamed: R19.2, S2.2 (D1)
unnamed: R18.2, S2.8 (D2)
unnamed: IC8.4 (INVERTING_INPUT), R21.2, R22.1
unnamed: IC8.1 (OUTPUT), R22.2, R23.1, R24.2
unnamed: IC8.3 (NONINVERTING_INPUT), IC9.1 (VOUT)
unnamed: R31.1, U6.5 (OUT)
unnamed: R32.2, U6.3 (IN+)
unnamed: IC12.1 (VOUT), U6.1 (IN-)
unnamed: C20.1, U3.9 (VRM)
unnamed: J4.33 (LED_A), R25.2
unnamed: C40.1, IC13.5 (CP)
unnamed: IC13.2 (FB+), R33.2, R36.2
unnamed: C41.1, IC14.4 (BYPASS)
unnamed: IC13.7 (FB-), R34.2, R35.2
unnamed: C38.1, IC13.10 (C1+)
unnamed: C38.2, IC13.9 (C1-)
unnamed: IC16.5 (A), R29.2
unnamed: R26.1, U3.24 (CLK)
RD: J4.12 (RD), U1.P$27 (GP21)
SCL: IC4.5 (SCL), IC9.5 (SCL), IC11.14 (SCL), IC12.5 (SCL), IC15.14 (SCL), R28.1, U1.P$22 (GP17), U4.2 (SCL)
SCLK: IC15.11 (P6), U7.P$4 (SCLK)
SDA: IC4.4 (SDA), IC9.4 (SDA), IC11.15 (SDA), IC12.4 (SDA), IC15.15 (SDA), R27.1, U1.P$21 (GP16), U4.1 (SDA)
SDATA: IC15.12 (P7), U7.P$3 (SDATA)
SEL: R29.1, U1.P$32 (GP27)
SEL0: IC11.10 (P5), S1.9 (IN1)
SEL1: IC11.9 (P4), S1.3 (IN2)
SEL2: IC11.6 (P2), S2.9 (IN1)
SEL3: IC11.7 (P3), S2.3 (IN2)
SWGND: U1.P$42 (SWGND)
TRIG: R31.2, U1.P$34 (GP28)
VIN: IC16.1 (COM), R32.1, U3.6 (VIN)
VINA: C8.1, D3.1 (C), IC16.7 (Y1), R11.2
VINB: C17.1, D6.1 (C), IC16.6 (Y2), R23.2
VREF: U3.3 (VRT), U5.1 (OUT), U5.4 (IN-)
VSYS: U1.P$39 (VSYS)
WR: J4.11 (WR), U1.P$26 (GP20)
X+: J4.3 (X+), U4.13 (X+)
X-: J4.1 (X-), U4.16 (X-)
Y+: J4.4 (Y+), U4.14 (Y+)
Y-: J4.2 (Y-), U4.17 (Y-)

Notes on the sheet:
CH1
BNC
AC/DC
High-Z
Switch
GAIN
Offset
DAC
CH2
MUX

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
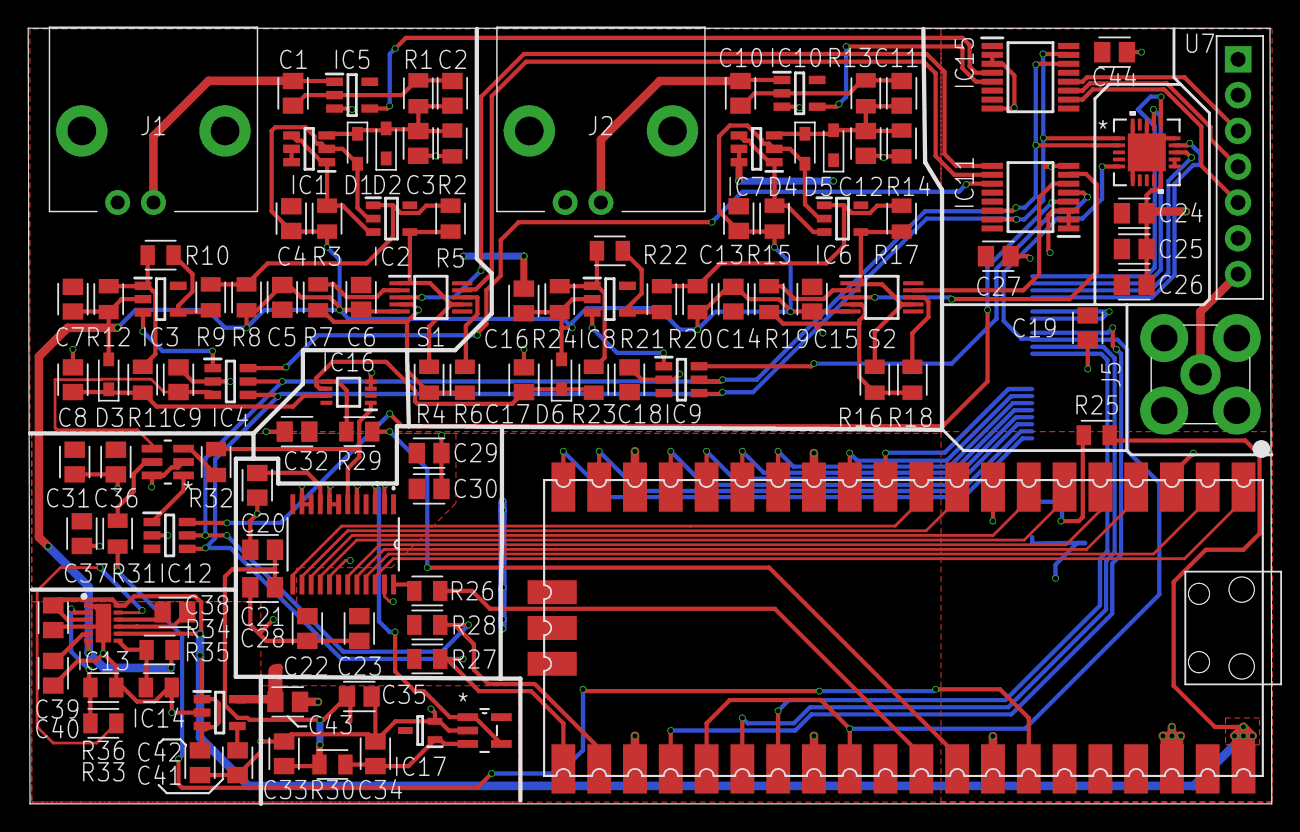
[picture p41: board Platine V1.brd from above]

Board: 2 copper layers, 88.2 x 55.0 mm, 115 parts (1 on the bottom side), 87 nets.

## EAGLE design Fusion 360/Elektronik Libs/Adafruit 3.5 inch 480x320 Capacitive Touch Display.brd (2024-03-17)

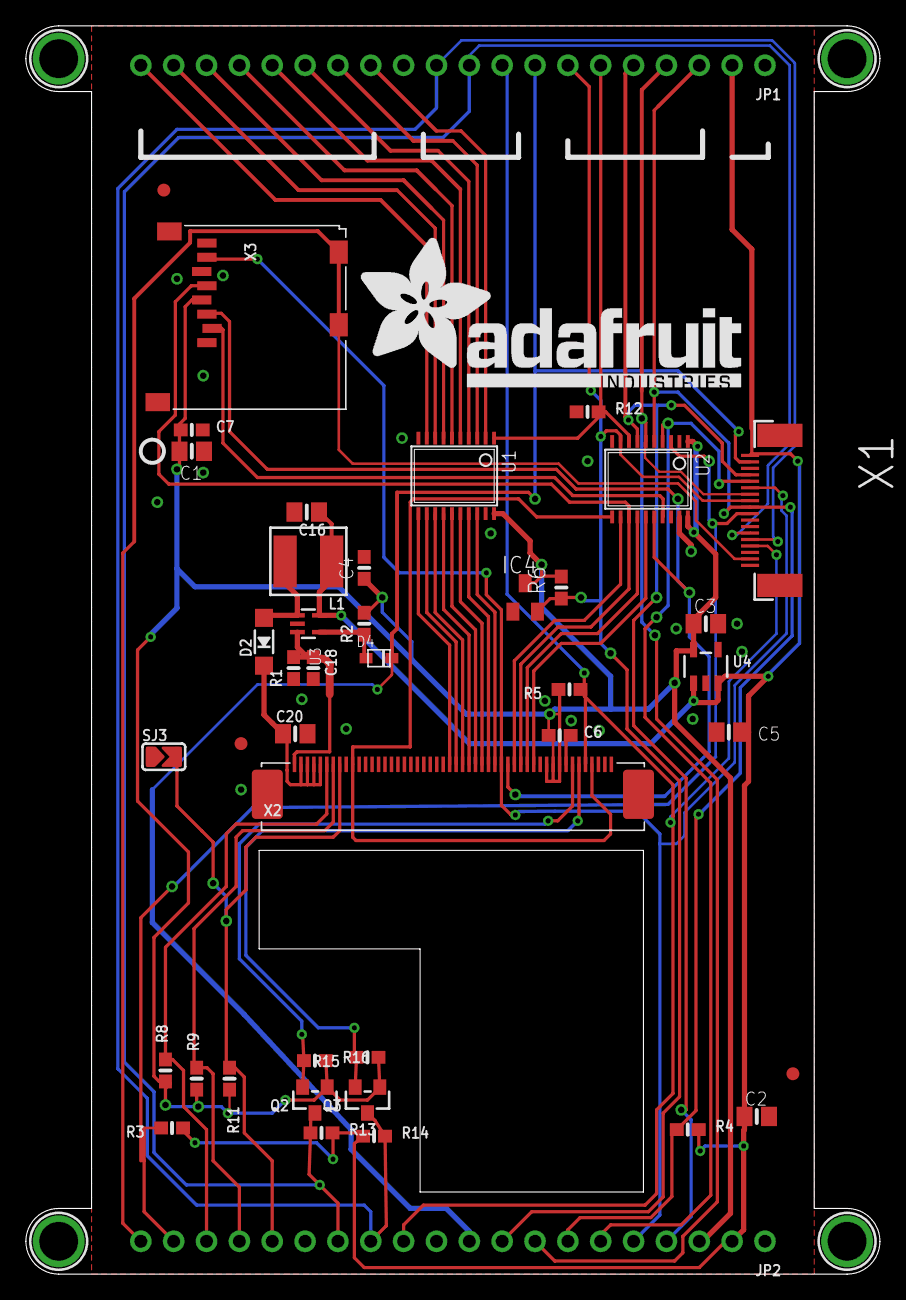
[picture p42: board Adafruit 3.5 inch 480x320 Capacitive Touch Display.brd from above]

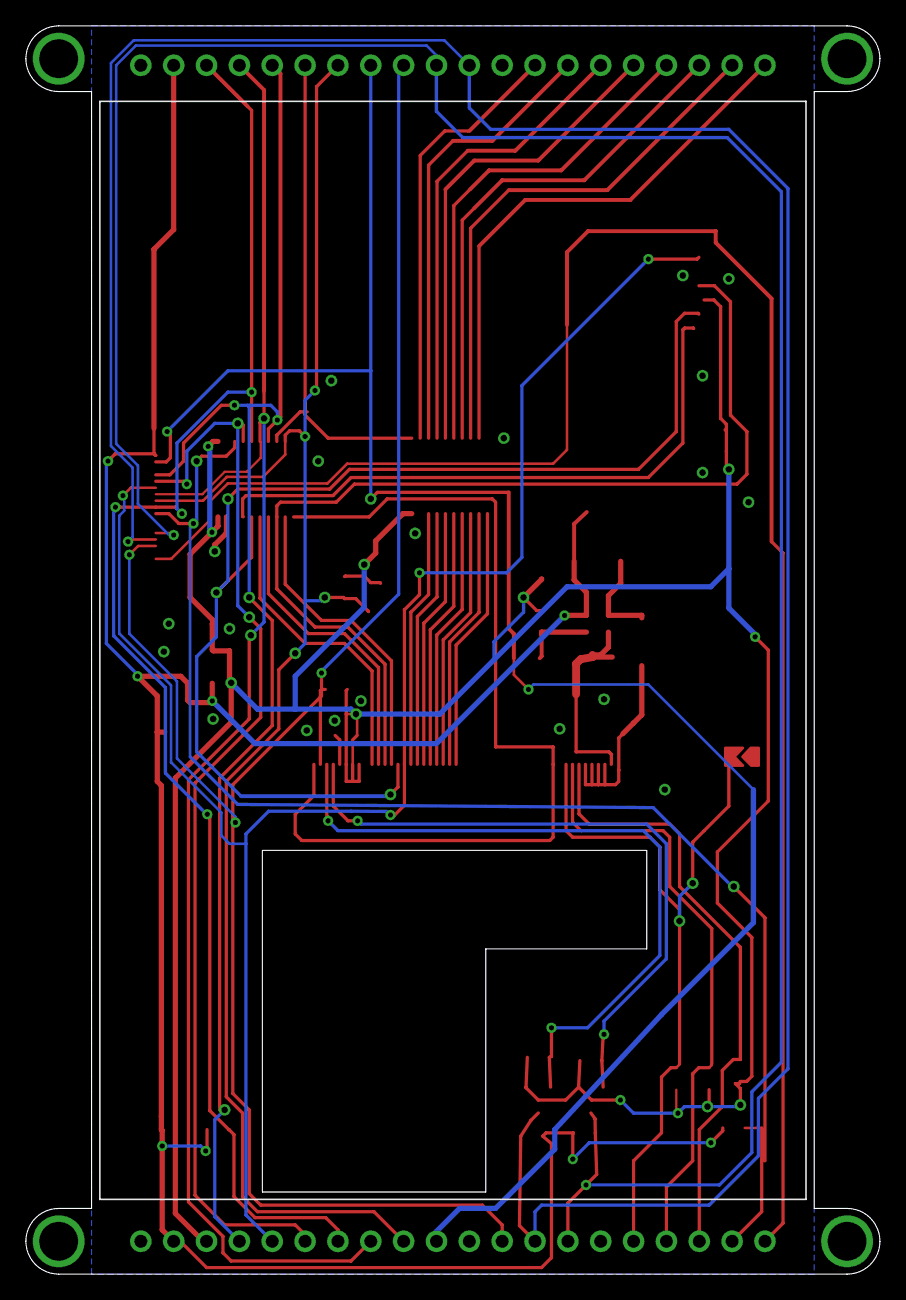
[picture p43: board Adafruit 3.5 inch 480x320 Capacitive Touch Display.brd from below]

Board: 2 copper layers, 66.0 x 96.5 mm, 143 parts (41 on the bottom side), 48 nets.

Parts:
C1, C2, C3, C5, C16: 10uF; 0805-NO
C4, C6, C7, C18: 0.1uF; 0603-NO
C20: 1uF; 0805-NO
D2: MBR0540; SOD-123
D4: 1N4148; SOD-323F
IC4: APX803-SAG; SOT23
JP1, JP2: 1X20_ROUND
L1: 6.8uH inductor; INDUCTOR_5X5MM_NR5040_NOTHERMALS
PLABEL0: PLABEL0
PLABEL1: PLABEL1
PLABEL2: PLABEL2
PLABEL3: PLABEL3
PLABEL4: PLABEL4
PLABEL5: PLABEL5
PLABEL6: PLABEL6
PLABEL7: PLABEL7
PLABEL8: PLABEL8
PLABEL9: PLABEL9
PLABEL10: PLABEL10
PLABEL11: PLABEL11
PLABEL12: PLABEL12
PLABEL13: PLABEL13
PLABEL14: PLABEL14
PLABEL15: PLABEL15
PLABEL16: PLABEL16
PLABEL17: PLABEL17
PLABEL18: PLABEL18
PLABEL19: PLABEL19
PLABEL20: PLABEL20
PLABEL21: PLABEL21
PLABEL22: PLABEL22
PLABEL23: PLABEL23
PLABEL24: PLABEL24
PLABEL25: PLABEL25
PLABEL26: PLABEL26
PLABEL27: PLABEL27
PLABEL28: PLABEL28
PLABEL29: PLABEL29
PLABEL30: PLABEL30
PLABEL31: PLABEL31
PLABEL32: PLABEL32
PLABEL33: PLABEL33
PLABEL34: PLABEL34
PLABEL35: PLABEL35
PLABEL36: PLABEL36
PLABEL37: PLABEL37
PLABEL38: PLABEL38
PLABEL39: PLABEL39
PLABEL40: PLABEL40
PLABEL41: PLABEL41
PLABEL42: PLABEL42
PLABEL43: PLABEL43
PLABEL44: PLABEL44
PLABEL45: PLABEL45
PLABEL46: PLABEL46
PLABEL47: PLABEL47
PLABEL48: PLABEL48
PLABEL49: PLABEL49
PLABEL50: PLABEL50
PLABEL51: PLABEL51
PLABEL52: PLABEL52
PLABEL53: PLABEL53
PLABEL54: PLABEL54
PLABEL55: PLABEL55
PLABEL56: PLABEL56
PLABEL57: PLABEL57
PLABEL58: PLABEL58
PLABEL59: PLABEL59
PLABEL60: PLABEL60
PLABEL61: PLABEL61
PLABEL62: PLABEL62
PLABEL63: PLABEL63
PLABEL64: PLABEL64
PLABEL65: PLABEL65
PLABEL66: PLABEL66
PLABEL67: PLABEL67
PLABEL68: PLABEL68
PLABEL69: PLABEL69
PLABEL70: PLABEL70
PLABEL71: PLABEL71
PLABEL72: PLABEL72
PLABEL73: PLABEL73
PLABEL74: PLABEL74
PLABEL75: PLABEL75
PLABEL76: PLABEL76
PLABEL77: PLABEL77
PLABEL78: PLABEL78
PLABEL79: PLABEL79
PLABEL80: PLABEL80
PLABEL81: PLABEL81
PLABEL82: PLABEL82
PLABEL83: PLABEL83
PLABEL84: PLABEL84
PLABEL85: PLABEL85
PLABEL86: PLABEL86
PLABEL87: PLABEL87
PLABEL88: PLABEL88
PLABEL89: PLABEL89
PLABEL90: PLABEL90
PLABEL91: PLABEL91
PLABEL92: PLABEL92
PLABEL93: PLABEL93
Q2, Q3: BSS138; SOT23-WIDE
R1: 8.2 ohm; 0603-NO
R2, R3, R4, R5, R6, R8, R9, R11, R12, R13, R14, R15, R16: 10K; 0603-NO
SJ3: SOLDERJUMPER_ARROW_NOPASTE
U1, U2: 74LVC245; TSSOP20
U3: tps61169; SC70-5
U4: AP2112K-3.3; SOT23-5
U$7, U$15, U$16, U$17: MOUNTINGHOLE3.0THIN; MOUNTINGHOLE_3.0_PLATEDTHIN
U$9, U$11, U$23: FIDUCIAL_1MM
U$19: ADAFRUIT_TEXT_30MM
U$31: PCBFEAT-REV-040
X1: EYE_SPI_DISPLAY_FLIP; EYE_SPI_DISPLAY_BOTCONTACT
X2: DISP_LCD_3.5IN_320X480CTP_50PIN; TFT_3.5IN_320X480_50PIN
X3: MICROSD

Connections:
+5V: C2.1, C5.1, C16.1, JP1.2, JP2.2, L1.P$1, R3.1, R4.2, R13.2, R14.1, U3.5, U4.1, U4.3, X1.1
+24V: C20.1, D2.C, X2.2, X2.3, X2.4, X2.5
CARDDET: JP2.20, X1.17, X3.CD1, X3.CD2
CTP_IRQ: JP1.9, JP2.12, R5.1, X1.15, X2.46
CTP_SCL_3V: Q2.2, R16.1, X2.44
CTP_SCL_5V: JP1.10, JP2.14, Q2.3, R13.1, X1.13
CTP_SDA_3V: Q3.2, R15.2, X2.45
CTP_SDA_5V: JP1.11, JP2.13, Q3.3, R14.2, X1.14
GND: C1.2, C2.2, C3.2, C4.2, C5.2, C6.2, C7.2, C16.2, C18.2, C20.2, IC4.1, JP1.1, JP1.12, JP2.1, JP2.11, JP2.15, R1.1, R12.1, SJ3.1, U1.10, U1.19, U2.10, U2.19, U3.2, U4.2, X1.3, X1.SUPPORT1, X1.SUPPORT2, X2.43, X2.48, X2.49, X2.50, X3.6, X3.MT1, X3.MT2
IM0: JP2.18, R8.2, X2.6
IM1: JP2.17, R9.2, X2.7
IM2: JP2.16, R11.1, SJ3.2, X2.8
LCD_CS: U2.15, X2.38
LCD_CS_5V: JP1.3, JP2.7, R4.1, U2.5, X1.9
LCD_DATA0: U1.18, X2.32
LCD_DATA0_5V: JP1.13, U1.2
LCD_DATA1: U1.17, X2.31
LCD_DATA1_5V: JP1.14, U1.3
LCD_DATA2: U1.16, X2.30
LCD_DATA2_5V: JP1.15, U1.4
LCD_DATA3: U1.15, X2.29
LCD_DATA3_5V: JP1.16, U1.5
LCD_DATA4: U1.14, X2.28
LCD_DATA4_5V: JP1.17, U1.6
LCD_DATA5: U1.13, X2.27
LCD_DATA5_5V: JP1.18, U1.7
LCD_DATA6: U1.12, X2.26
LCD_DATA6_5V: JP1.19, U1.8
LCD_DATA7: U1.11, X2.25
LCD_DATA7_5V: JP1.20, U1.9
LCD_LITE: D4.C, JP1.8, JP2.10, X1.2
LCD_RD: U2.12, X2.35
LCD_RD_5V: JP1.6, R12.2, U1.1, U2.8
LCD_RS: U2.14, X2.37
LCD_RST: U2.11, X2.10, X2.47
LCD_RST_5V: IC4.2, JP1.7, JP2.9, R6.1, U2.9, X1.8
LCD_RS_5V: JP1.4, JP2.8, U2.6, X1.7
LCD_WR: U2.13, X2.36, X3.5
LCD_WR_5V: JP1.5, JP2.4, U2.7, X1.4
LEDK: C18.1, R1.2, U3.3, X2.1
unnamed: D2.A, L1.P$2, U3.1
SDI_3V: U2.16, X2.34, X3.3
SDI_5V: JP2.6, U2.4, X1.5
SDO: JP2.5, X1.6, X2.33, X3.7
SD_CS_3V: U2.17, X3.2
SD_CS_5V: JP2.19, R3.2, U2.3, X1.10
SHDN: D4.A, R2.1, U3.4
VCC: C1.1, C3.1, C4.1, C6.1, C7.1, IC4.3, JP2.3, Q2.1, Q3.1, R2.2, R5.2, R6.2, R8.1, R9.1, R11.2, R15.1, R16.2, U1.20, U2.1, U2.20, U4.5, X2.40, X2.41, X2.42, X3.4

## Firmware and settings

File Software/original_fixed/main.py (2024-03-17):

import time
time.sleep(2)
import machine
import uasyncio as asyncio
import lvgl as lv
from hal.ili9488 import Ili9488
from hal.xpt2046 import Xpt2046
from hal.adc08100 import Adc08100
from gui.display_driver_utils import Display_Driver
from gui.async_utils import Lv_Async
import scope

import gc
gc.collect()
gc.threshold( gc.mem_free() // 4 + gc.mem_alloc() )

import machine
machine.freq( 200_000_000 )

lcd_baudrate = 24_000_000
tsc_baudrate = 1_000_000
adc_frequency = 10_000_000
pwm_frequency = 1_000_000

spi_sck = machine.Pin( 10, machine.Pin.OUT )
spi_mosi= machine.Pin( 11, machine.Pin.OUT )
spi_miso= machine.Pin( 12, machine.Pin.IN   )
spi_dc  = machine.Pin( 8, machine.Pin.OUT )

lcd_rst = machine.Pin( 15, machine.Pin.OUT )
lcd_bl  = machine.Pin( 13, machine.Pin.OUT )
lcd_cs  = machine.Pin( 9, machine.Pin.OUT )
tsc_cs  = machine.Pin( 16, machine.Pin.OUT )

adc_sck = machine.Pin( 21 )
mux_sel = machine.Pin( 20 )
adc_db  = machine.Pin( 0 ) # 0..7 pins are used

trig_pin = machine.Pin( 18 )
trig_pwm = machine.PWM( trig_pin )

trig_pwm.freq( pwm_frequency )
trig_pwm.duty_u16( int(0xFFFF*1.024/3.3) )

# Calibration values
print( "tsc()" )
AX, BX = 0.2525,-29.545
AY, BY =-0.1744, 335.52
tsc = Xpt2046( tsc_baudrate, tsc_cs, spi_sck, spi_mosi, spi_miso, ax=AX, bx=BX, ay=AY, by=BY )

# Init lcd last one to start lvgl with SPI LCD baudrate
print( "lcd()" )
lcd = Ili9488( lcd_baudrate, lcd_cs, spi_sck, spi_mosi, spi_miso, spi_dc, lcd_rst, lcd_bl )

print( "adc()" )
adc = Adc08100( adc_frequency, adc_sck, adc_db )

print( "lvgl" )
display_driver = Display_Driver( 480, 320, lcd, tsc )

print( "build" )
scr = lv.obj()
my_scope = scope.Scope( scr, adc, trig_pwm, display_driver, 1024, 256 )#480-160 )
lv.scr_load( scr )

timer = lv.timer_create_basic()
timer.set_period( 50 )
timer.set_cb( lambda tmr: my_scope.process() )

print( "run" )
lva = Lv_Async( refresh_rate=20 )
asyncio.Loop.run_forever()

timer.set_cb( None )

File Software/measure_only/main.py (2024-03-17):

import time
time.sleep(2)
import machine
import uasyncio as asyncio
from hal.adc08100 import Adc08100
import scope

import gc
gc.collect()
gc.threshold( gc.mem_free() // 4 + gc.mem_alloc() )

import machine
machine.freq( 200_000_000 )

adc_frequency = 1_000_000
pwm_frequency = 1_000_000


adc_sck = machine.Pin( 26 )
mux_sel = machine.Pin( 27 )
adc_db  = machine.Pin( 0 ) # 0..7 pins are used

trig_pin = machine.Pin( 8 )
trig_pwm = machine.PWM( trig_pin )

trig_pwm.freq( pwm_frequency )
trig_pwm.duty_u16( int(0xFFFF*1.024/3.3) )

print( "adc()" )
adc = Adc08100( adc_frequency, adc_sck, adc_db )

print( "Messung")
my_scope = scope.Scope(adc, trig_pwm, 1, 1024, 256 )#480-160 )
        

print( "run" )

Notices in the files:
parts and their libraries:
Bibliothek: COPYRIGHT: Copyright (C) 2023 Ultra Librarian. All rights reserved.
